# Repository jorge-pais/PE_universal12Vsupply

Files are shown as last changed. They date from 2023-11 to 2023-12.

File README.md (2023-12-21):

# Power Electronics - Final Project

This project is a simple and efficient universal 12V switch mode power supply circuit, designed and built for the final project of the Power Electronics Course at KU Leuven - Group T. It is designed around Texas Instruments' LM5175 buck-boost controller IC in order to provide currents up to 2A with an input voltage ranging from 4V to 24V.

## Circuit and PCB

Both the schematic capture and PCB design were done utilizing KiCad 7. These project files can be found the `universal12Vsupply` folder.

It is possible to preview the project online without KiCad through [KiCanvas](https://kicanvas.org/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).

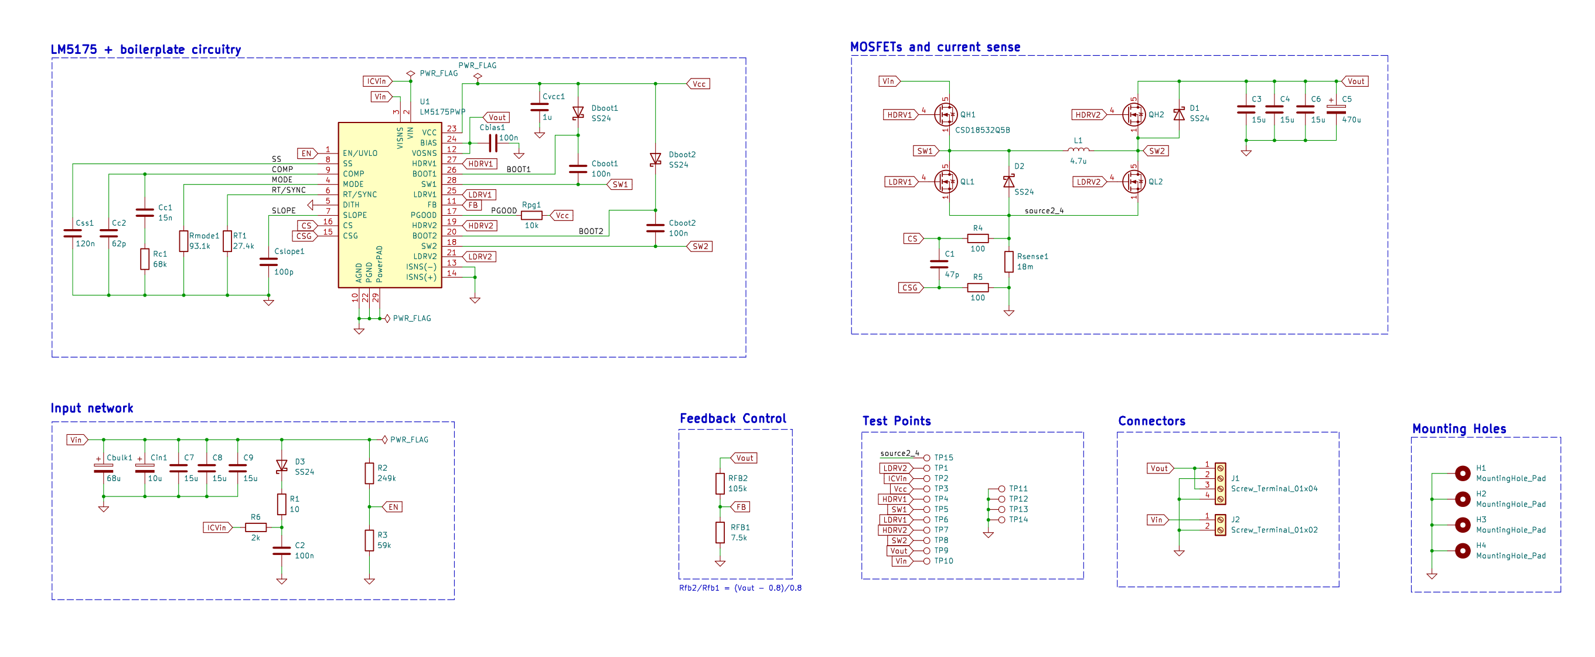
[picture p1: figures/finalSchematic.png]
Circuit schematic


#### Front View

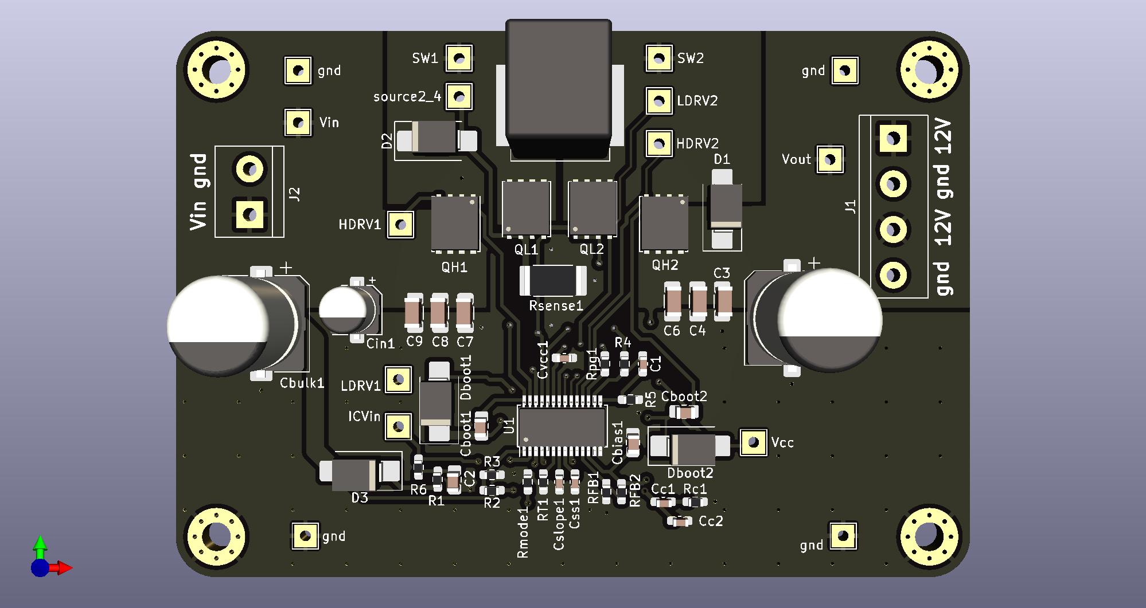
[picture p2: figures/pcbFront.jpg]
Front view of the PCB


#### Back View

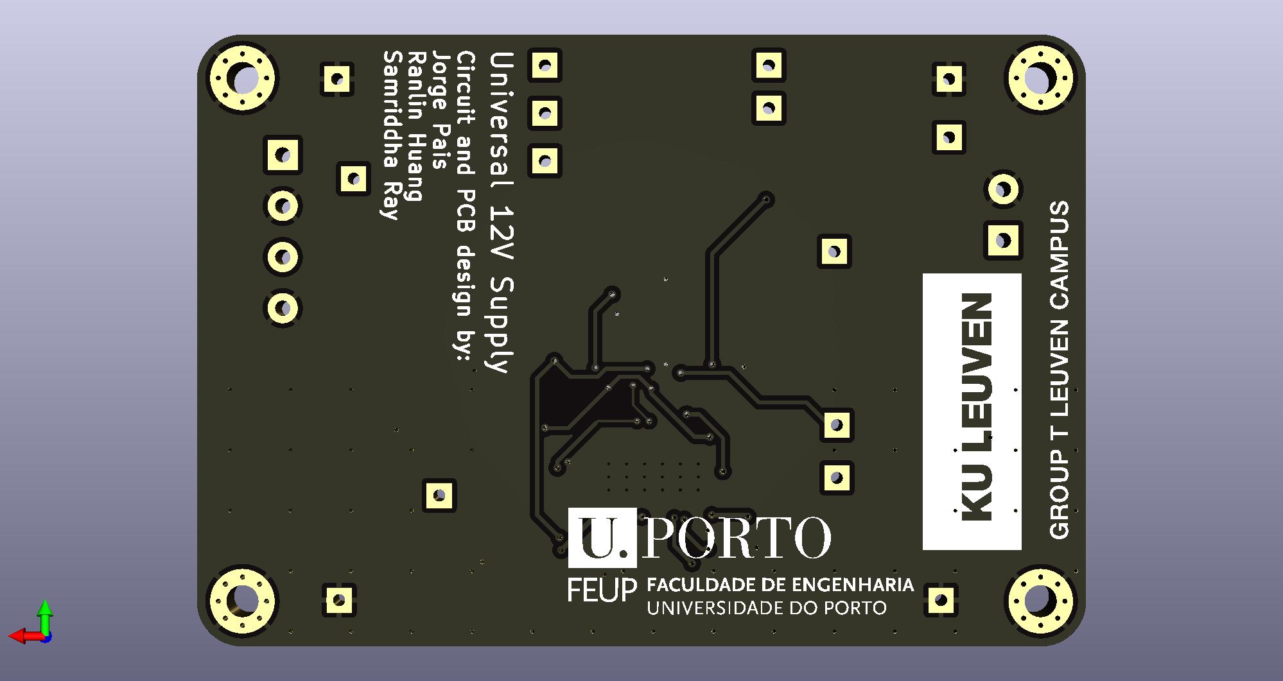
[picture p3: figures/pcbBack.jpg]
Back view of the PCB


## Credits

This project was the collaborative effort of the following team members:

- Jorge Pais
- Ranlin Huang
- Samriddha Ray

Their hard work and dedication made this project a success.

## License

This project is licensed under the [Open Source Hardware License 2](LICENSE.md)

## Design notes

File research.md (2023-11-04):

# Power Electronics Project

***Theme:*** Universal 12V supply. IN: 5-18V. OUT: 12V, 1A

For all the calculations, the components were overdimensioned considering IN: 4-24V and Iout of 2A  

Given the input/output requirements, a step-up-down configuration is needed. By looking at some major manufacturers of power management ICs, the LM5176 buck-boost controller was chosen because although it requires external switching through MOSFETs.

https://be.farnell.com/en-BE/texas-instruments/lm5176pwpt/dc-dc-ctrl-sync-buck-boost-htssop/dp/3008671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

In the datasheet, a simple buck boost implementation is shown as figure 8-1.

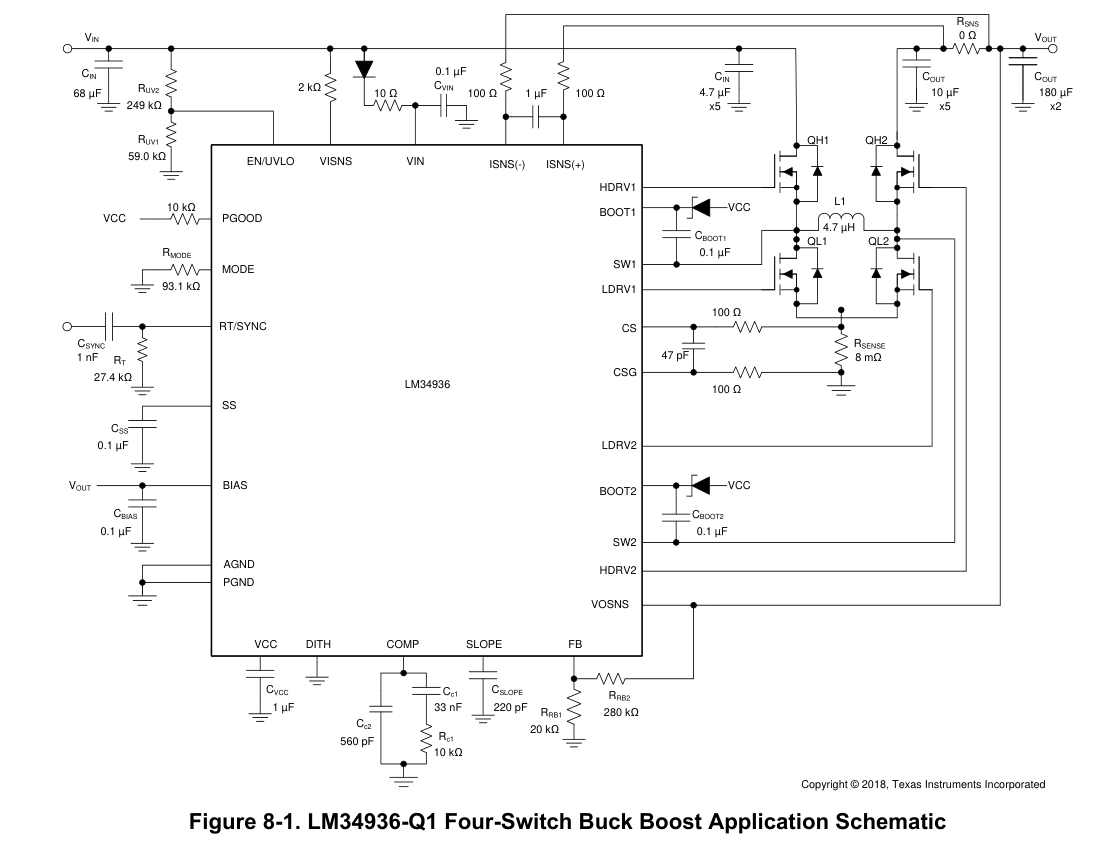
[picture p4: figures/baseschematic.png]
Buck Boost Application Schamatic


### Design

#### Frequency

As per the majority datasheet information and examples, we'll use a switching frequency $F_{SW} = 300 \text{kHz}$. As such, the $R_{T}$ resistor must be of value $27.4\text k \Omega$.

#### Vout

The output voltage is set using a resistor devider to the FB pin. The internal reference voltage is 0.8V.

$$\frac{R_{FB2}}{R_{FB1}} = \frac{V_{out}-0.8}{0.8} = 14$$

If we use resistors from the E48 value series we get a perfect resistor ratio using:

$$R_{FB1} = 7.5 \text k \Omega; R_{FB2} = 105 \text k \Omega$$

#### Inductor Selection

The target inductance for Buck mode is:

$$L_{buck} = \frac{(V_{inMAX}-V_{out})V_{out}}{0.4I_{outMAX}F_{SW}V_{inMAX}} = 25 \mu \text H$$

And the target inductance for boost mode is:

$$L_{boost} = \frac{V_{inMIN}^2 (V_{out}-V_{inMIN})}{0.3I_{outMAX}F_{SW}V_{out}^2}= 4.93 \mu \text H$$

And the maximum average inductor current is (assuming 90\%) efficiency:

$$I_{Lmax} = \frac{V_{out}I_{outMAX}}{0.9V_{inMIN}}= 6.66\text A$$

Given this, and that the datasheet also under specs this component quite a bit, the following $4.7\mu \text H$ inductor can be utilized: https://be.farnell.com/en-BE/bourns/srp1038a-4r7m/inductor-4-7uh-20-10a-shielded/dp/2434028

$$I_{Lpeak} = I_{Lmax} \frac{V_{inMIN}(V_{out}-V_{inMIN})}{2L_1F_{sw}V_{out}} \approx 6.66 \text A$$

#### Output Capacitor

The output capacitor can be determined by the capacitive ripple voltage:

$$\Delta V_{ripple} = \frac{I_{out}(1-\frac{V_{inMIN}}{V_{out}})}{C_{out}F_{SW}}$$

So for a 10 mV ripple from the capacitor, a value of $444.44\mu \text F$ is required. As such $C_{out} = 470\mu \text F$  

#### MOSFETs
The csd18532 is a good mosfet option with high current handling capabilities and and enough Vds to handle the maximum input voltage.
https://be.farnell.com/en-BE/texas-instruments/csd18532q5b/mosfet-n-ch-60v-100a-vson-8/dp/3009663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

#### Rsense

$$R_{senseBUCK} = \frac{80\text{mV}}{I_{outMAX}} = 40\text m\Omega$$

$$R_{senseBOOST} = \frac{120\text{mV}}{I_{Lpeak}} = 18\text m\Omega$$

This value is then set to $R_{sense} = 18\text m\Omega$ based on the boost mode operation.

The power loss experienced by the $R_{sense}$ is the following:

$$P_{senseMAX} = (120mV/R_{sense})^2*R_{sense}*(1-V_{inMIN}/V_{out}) = 0.53 \text W$$

Hence a 1W sense resistor is sufficient

#### Frequency Compensation

At the maximum load of 2A, output resistance is $R_{out} = V_{out}/I_{outMAX} 6\Omega$

$$f_{p1(boost)} = \frac{2}{2\pi R_{out}C_{out}} = 112 \text{Hz}$$

$$f_{z1} = \frac{1}{2\pi R_{esr}C_{out}} = 226 \text{Hz} $$

The boost power stage RHP zero location is given by: 

$$f_{RHP} = \frac{R_{out}(1-D_{max})^2}{2\pi L_1} = 22.57\text{kHz}$$

Where $D_{max}$ is the maximum duty cycle at the minimum $V_{in}$: $D = 1-\frac{V_i}{V_o} = 0.667$ 

$$f_{p1(buck)} = \frac{1}{2\pi R_{out}C_{out}} = 56.4379$$

From these, it is clear that the RHP zero is the main factor limiting the achievable bandwidth.

$$f_{bw} = \frac{f_{RHP}}{3} = 7.52\text{kHz}$$

The compensation zero can be placed at 1.5 times the boost frequency pole.

$$f_{zc} = 1.5f_{p1(boost)} = 168\text{Hz}$$

Then the values for $R_{c1}, C_{c1} and C_{c2}$ can be figured out through the following expressions:

$$R_{c1} = \frac{2\pi f_{bw}}{gm_{EA}}\frac{R_{FB1}+R_{FB2}}{R_{FB1}}\frac{A_{cs}R_{sense}C_{out}}{1-D_{max}} = 68656\Omega \approx 68\text k \Omega$$

$$C_{c1} = \frac{1}{2\pi f_{zc} R_{c1}} = 13.79 \text{nF} \approx 13 \text{nF}$$

$$C_{c2} = \frac{1}{2\pi 5 f_{bw} R_{c1}} = 61.65 \text{pF} \approx 62 \text{pF}$$

#### Soft start

For a 20ms soft-start:

$I_{ss} = 5\mu \text A$

$$C_{ss} = \frac{t_{ss}I_{ss}}{V_{ref}} = 125 nF = 120n $$

#### Slope compensation

$$C_{slope} = gm_{slope}\frac{L1}{R_{sense}A_{cs}} = 100pF$$

#### Diodes

For all the diodes needed by the circuit, the MULTICOMP PRO SS24 schottky barrier rectifier was selected:

https://be.farnell.com/en-BE/multicomp/ss24/schottky-rectifier-2a-40v-do-214aa/dp/2675138?MER=sy-me-pd-mi-alte

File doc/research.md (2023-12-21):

# Power Electronics Project - Design

***Theme:*** Universal 12V supply. IN: 5-18V. OUT: 12V, 1A

For all the calculations, the components were overdimensioned considering IN: 4-24V and Iout of 2A  

Given the input/output requirements, a step-up-down configuration is needed. By looking at some major manufacturers of power management ICs, the LM5176 buck-boost controller was chosen because although it requires external switching through MOSFETs.

https://be.farnell.com/en-BE/texas-instruments/lm5176pwpt/dc-dc-ctrl-sync-buck-boost-htssop/dp/3008671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

In the datasheet, a simple buck boost implementation is shown as figure 8-1.

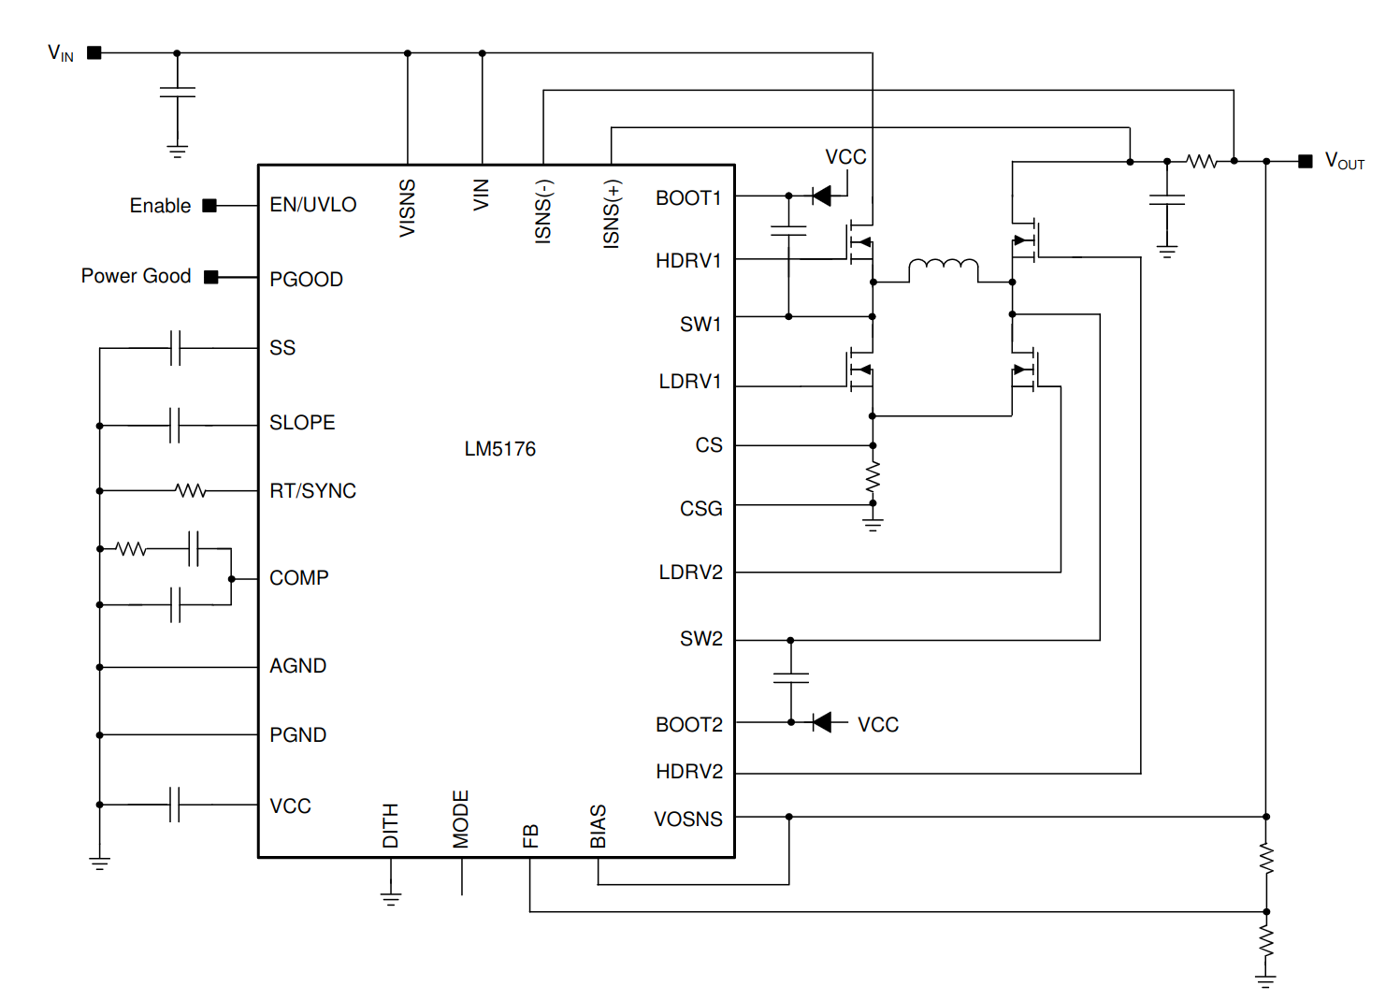
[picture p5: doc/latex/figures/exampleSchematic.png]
Buck Boost Application Schamatic


### Design

#### Frequency

As per the majority datasheet information and examples, we'll use a switching frequency $F_{SW} = 300 \text{kHz}$. As such, the $R_{T}$ resistor must be of value $27.4\text k \Omega$.

#### Vout

The output voltage is set using a resistor devider to the FB pin. The internal reference voltage is 0.8V.

$$\frac{R_{FB2}}{R_{FB1}} = \frac{V_{out}-0.8}{0.8} = 14$$

If we use resistors from the E48 value series we get a perfect resistor ratio using:

$$R_{FB1} = 7.5 \text k \Omega; R_{FB2} = 105 \text k \Omega$$

#### Inductor Selection

The target inductance for Buck mode is:

$$L_{buck} = \frac{(V_{inMAX}-V_{out})V_{out}}{0.4I_{outMAX}F_{SW}V_{inMAX}} = 25 \mu \text H$$

And the target inductance for boost mode is:

$$L_{boost} = \frac{V_{inMIN}^2 (V_{out}-V_{inMIN})}{0.3I_{outMAX}F_{SW}V_{out}^2}= 4.93 \mu \text H$$

And the maximum average inductor current is (assuming 90\%) efficiency:

$$I_{Lmax} = \frac{V_{out}I_{outMAX}}{0.9V_{inMIN}}= 6.66\text A$$

Given this, and that the datasheet also under specs this component quite a bit, the following $4.7\mu \text H$ inductor can be utilized: https://be.farnell.com/en-BE/bourns/srp1038a-4r7m/inductor-4-7uh-20-10a-shielded/dp/2434028

$$I_{Lpeak} = I_{Lmax} + \frac{V_{inMIN}(V_{out}-V_{inMIN})}{2L_1F_{sw}V_{out}} \approx 6.66 \text A$$

#### Output Capacitor

The output capacitor can be determined by the capacitive ripple voltage:

$$\Delta V_{ripple} = \frac{I_{out}(1-\frac{V_{inMIN}}{V_{out}})}{C_{out}F_{SW}}$$

So for a 10 mV ripple from the capacitor, a value of $444.44\mu \text F$ is required. As such $C_{out} = 470\mu \text F$  

#### MOSFETs
The csd18532 is a good mosfet option with high current handling capabilities and and enough Vds to handle the maximum input voltage.
https://be.farnell.com/en-BE/texas-instruments/csd18532q5b/mosfet-n-ch-60v-100a-vson-8/dp/3009663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

#### Rsense

$$R_{senseBUCK} = \frac{80\text{mV}}{I_{outMAX}} = 40\text m\Omega$$

$$R_{senseBOOST} = \frac{120\text{mV}}{I_{Lpeak}} = 18\text m\Omega$$

This value is then set to $R_{sense} = 18\text m\Omega$ based on the boost mode operation.

The power loss experienced by the $R_{sense}$ is the following:

$$P_{senseMAX} = (120mV/R_{sense})^2*R_{sense}*(1-V_{inMIN}/V_{out}) = 0.53 \text W$$

Hence a 1W sense resistor is sufficient

#### Frequency Compensation

At the maximum load of 2A, output resistance is $R_{out} = V_{out}/I_{outMAX} 6\Omega$

$$f_{p1(boost)} = \frac{2}{2\pi R_{out}C_{out}} = 112 \text{Hz}$$

$$f_{z1} = \frac{1}{2\pi R_{esr}C_{out}} = 226 \text{Hz} $$

The boost power stage RHP zero location is given by: 

$$f_{RHP} = \frac{R_{out}(1-D_{max})^2}{2\pi L_1} = 22.57\text{kHz}$$

Where $D_{max}$ is the maximum duty cycle at the minimum $V_{in}$: $D = 1-\frac{V_i}{V_o} = 0.667$ 

$$f_{p1(buck)} = \frac{1}{2\pi R_{out}C_{out}} = 56.4379$$

From these, it is clear that the RHP zero is the main factor limiting the achievable bandwidth.

$$f_{bw} = \frac{f_{RHP}}{3} = 7.52\text{kHz}$$

The compensation zero can be placed at 1.5 times the boost frequency pole.

$$f_{zc} = 1.5f_{p1(boost)} = 168\text{Hz}$$

Then the values for $R_{c1}, C_{c1} and C_{c2}$ can be figured out through the following expressions:

$$R_{c1} = \frac{2\pi f_{bw}}{gm_{EA}}\frac{R_{FB1}+R_{FB2}}{R_{FB1}}\frac{A_{cs}R_{sense}C_{out}}{1-D_{max}} = 68656\Omega \approx 68\text k \Omega$$

$$C_{c1} = \frac{1}{2\pi f_{zc} R_{c1}} = 13.79 \text{nF} \approx 13 \text{nF}$$

$$C_{c2} = \frac{1}{2\pi 5 f_{bw} R_{c1}} = 61.65 \text{pF} \approx 62 \text{pF}$$

#### Soft start

For a 20ms soft-start:

$I_{ss} = 5\mu \text A$

$$C_{ss} = \frac{t_{ss}I_{ss}}{V_{ref}} = 125 nF = 120n $$

#### Slope compensation

$$C_{slope} = gm_{slope}\frac{L1}{R_{sense}A_{cs}} = 100pF$$

#### Diodes

For all the diodes needed by the circuit, the MULTICOMP PRO SS24 schottky barrier rectifier was selected:

https://be.farnell.com/en-BE/multicomp/ss24/schottky-rectifier-2a-40v-do-214aa/dp/2675138?MER=sy-me-pd-mi-alte

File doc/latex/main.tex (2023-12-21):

\documentclass[11pt, a4paper]{article}

\usepackage[T1]{fontenc}
\usepackage[utf8]{inputenc}

\usepackage{verbatim}
\usepackage{amsmath}
%\usepackage{biblatex} 
\usepackage{graphicx}   
\usepackage{float}
\usepackage{appendix}   
\usepackage{listings}   
\usepackage{xcolor}
\usepackage{siunitx}
\usepackage{pdfpages}
\usepackage{textcomp, gensymb}
\usepackage{multirow}

\sisetup{detect-all}

\usepackage[
backend=biber,
style=ieee,
sorting=ynt
]{biblatex}

\addbibresource{1.bib}

\title{Power Electronics - 12V Universal Supply \\ Design and Measurement Report}
\author{Jorge Pais \\ Ranlin Huang \\ Samriddha Ray }
\date{December 2023}

\begin{document}

\maketitle
\vfill \pagebreak
\tableofcontents
\vfill \pagebreak

\section{Introduction/Specification}

Our project proposed for the power electronics course unit was the universal 12V power supply. The original specifications were as follows:

\begin{itemize}
    \item Output voltage: 12V
    \item Input voltage : min. 5V; max. 18V
    \item Output Current: 1A 
\end{itemize}

Considering these, the team attempted to overdimension the circuit in order to output more current (2A) and accept a higher range of input voltages (min. 5V and max. 24V).

\section{Design}

\subsection{Circuit}

As the basis for the design, the LM5175 buck-boost converter controller by Texas Instruments \cite{lm7175data} was chosen. Since the design requires 2A of output current, a externally switched solution is a safer approach and as such the LM5175 presents a relatively modern design without many features such as $\text I^2\text C$ that would not be utilized. Also the four switch buck-boost converter approach as some advantages over traditional single or dual switch topologies, since at any given time two of the MOSFETs are in either on or off state while the other commutate. This has the benefit that no diodes are needed, and thus lower forward voltage drops are present in both modes of operation.

An example circuit schematic for the circuit can be seen in figure \ref{fig:exampleSchem}. The circuit developed is based around this initial design and uses follows the dimensioning procedure that is described in the IC's datasheet \cite{lm7175data}.

\begin{figure}[H]
    \centering
    
    \caption{Simplified LM5175 Schematic}
    \label{fig:exampleSchem}
\end{figure}

As for the final schematic, a simplified version without connectors and testpoints can be found at the end of this document as an appendix.

\subsubsection{Switching Frequency}

The LM5175's switching frequency can be programmed between 100 and 600 kHz using a resistor from the RT/SYNC pin to ground. Higher values lead to higher overall efficiency but with added EMI and noise. The switching frequency was chosen to be 300kHz, as most examples featured in the datasheet used this value.

\begin{equation}
    R_T = \frac{1/F_{SW}-190\text{ns}}{116\text{pF}} = 27.4 \text k \Omega
\end{equation}

\subsubsection{Feedback Network}

The output voltage of the circuit is set using a the feedback network between the output and the IC's FB pin. 

\begin{equation}
    \frac{R_{FB2}}{R_{FB1}} = \frac{V_{out}-0.8}{0.8} = 14
\end{equation}

Choosing E48 series resistor values, a perfect ratio can be obtained:

$$R_{FB1} = 7.5 \text k \Omega; R_{FB2} = 105 \text k \Omega$$

\subsubsection{Inductor Selection}

The target inductance for Buck mode is given by the following formula:

\begin{equation}
    L_{buck} = \frac{(V_{inMAX}-V_{out})V_{out}}{0.4I_{outMAX}F_{SW}V_{inMAX}} = 25 \mu \text H
\end{equation}

And the target for boost mode is the following:

\begin{equation}
    L_{boost} = \frac{V_{inMIN}^2 (V_{out}-V_{inMIN})}{0.3I_{outMAX}F_{SW}V_{out}^2}= 4.93 \mu \text H
\end{equation}

The maximum average inductor current is the following if we assume 90\% efficiency:

\begin{equation}
    I_{Lmax} = \frac{V_{out}I_{outMAX}}{0.9V_{inMIN}}= 6.66\text A
\end{equation}

Given this, the datasheet actually under specifies this component. A $4.7\mu \text H$ inductor can be utilized and as such, the XAL1010-472MED from Coilcraft \cite{XAL1010data} was chosen.

As for the peak inductor following through the inductor it is:

\begin{equation}
    I_{Lpeak} = I_{Lmax} + \frac{V_{inMIN}(V_{out}-V_{inMIN})}{2L_1F_{sw}V_{out}} \approx 6.66 \text A  
\end{equation}

\subsubsection{Output Capacitors}

The value for the main output capacitor can be determined by the capacitive ripple voltage:

\begin{equation}
    \Delta V_{ripple} = \frac{I_{out}(1-\frac{V_{inMIN}}{V_{out}})}{C_{out}F_{SW}}
\end{equation}

And so, for a 10mV ripple from the capacitor, a value of $444.44\mu \text F$ is required. As such $C_{out} = 470\mu \text F$, which can be achieved with a small electrolytic capacitor. For this purpose Panasonic's 25SPVK470M Polymer Aluminum capacitor was chosen, which has a maximum voltage rating of 25V and a ESR of 14m$\Omega$.

Along side this, three smaller $15\mu \text F$ tantalum capacitors are placed in parallel, such as to minimize output ESR. So, the TPSA156K006R0700 from Kyocera Avx was chosen, each featuring an ESR of 7m$\Omega$. 

For the boost mode of operation the RMS current through the capacitor is given by:

\begin{equation}
    I_{Cout_{RMS}} = I_{out} \sqrt{\frac{V_{out}}{V_{in}}-1}
    \label{eq:coutIrms}
\end{equation}

\subsubsection{Input Capacitors}

As for the input capacitors, in the buck operating region, they need to be able to supply high ripple current. It's RMS current is given by the following equation, where the worst case scenario of D = 0.5 should be considered:

\begin{equation}
    I_{C_{in}rms} = I_{out} \sqrt{D(1-D)} = 1 A
    \label{eq:cinIrms}
\end{equation}

So in a similar fashion as for the output, a bulk electrolytic capacitor of $68\mu \text F$ was placed in parallel with several $15\mu \text F$ tantalum capacitors. The bulk capacitor chosen was the Panasonic EEHZT1J680P featuring a maximum voltage rating of 63V and a ESR of 25m$\Omega$.

\subsubsection{Current Limit}

The circuit's current limit is set by the $R_{sense}$ resistor at the tail of the 4 mosfet switch bridge.

\begin{equation}
    R_{senseBUCK} = \frac{80\text{mV}}{I_{outMAX}} = 40\text m\Omega
\end{equation}

\begin{equation}
    R_{senseBOOST} = \frac{120\text{mV}}{I_{Lpeak}} = 18\text m\Omega
\end{equation}

This value is then set to $R_{sense} = 18\text m\Omega$ based on the boost mode operation. The power loss experienced by the $R_{sense}$ is the following:

\begin{equation}
    P_{senseMAX} = \left (\frac{120mV}{R_{sense}}\right )^2R_{sense}\left (1-\frac{V_{inMIN}}{V_{out}}\right ) = 0.53 \text W
    \label{eq:rsensePower}
\end{equation}

Hence a 1W sense resistor is sufficient. As for the sense lines $R_{CS}$ and $R_{CSG}$ the values were chosen according to the example schematic provided on the datasheet: $R_{CS} = R_{CSG} = 100\Omega$. A filter capacitor is also needed to attenuate the noise that can occur in these lines due to the large amounts of current passing through $R_{sense}$, as such a 47pF capacitor is utilized as a part of a differential mode filter in the CS and CSG pins to the LM5175.

\subsubsection{MOSFETs}

The LM5175 features four built-in N-channel MOSFET gate drivers. In buck operation, QL1 and QH1 are switched by the IC's PWM controller while QH2 is continuously on and QL2 off. As for boost operation, QL2 and QH2 are switching while QH1 remains continuously on and QL2 is off.

For the QH1 and QL2 MOSFETs on the input side, these need to withstand the maximum input voltage of the circuit, plus the possible voltage transient spikes. Considering the extended specifications, this value comes to $V_{DS_{max}} \ge 24 + 20V$. As for the output, transistors QH2 and QL2 should be rated for 12V plus the transient spikes.

When choosing a MOSFET for this circuit, it is also important to consider the rise/fall time and gate charges of the transistor, in order to minimize switching time and thus minimize switching loss. Also, the drain-to-source on-resistance should be minimal in order to lower the conduction losses.

Considering these requirements, the MOSFET chosen for the 4 switches was the Texas Instruments' CSD18532Q5B n-channel MOSFET \cite{CSD18532data}, claiming to feature maximum $V_{gs}$ of 60V and ultra-low gate charges.

\subsubsection{Frequency Compensation}

At the maximum load of 2A, output resistance is $R_{out} = V_{out}/I_{outMAX} 6\Omega$

\begin{equation}
    f_{p1(boost)} = \frac{2}{2\pi R_{out}C_{out}} = 112 \text{Hz}    
\end{equation}

\begin{equation}
    f_{z1} = \frac{1}{2\pi R_{esr}C_{out}} = 226 \text{Hz}    
\end{equation}

The boost power stage RHP zero location is given by: 

\begin{equation}
    f_{RHP} = \frac{R_{out}(1-D_{max})^2}{2\pi L_1} = 22.57\text{kHz}
\end{equation}

Where $D_{max}$ is the maximum duty cycle at the minimum $V_{in}$: $D = 1-\frac{V_i}{V_o} = 0.667$ 

\begin{equation}
    f_{p1(buck)} = \frac{1}{2\pi R_{out}C_{out}} = 56.4379  
\end{equation}

From these, it is clear that the RHP zero is the main factor limiting the achievable bandwidth.

\begin{equation}
    f_{bw} = \frac{f_{RHP}}{3} = 7.52\text{kHz}    
\end{equation}

The compensation zero can be placed at 1.5 times the boost frequency pole.

\begin{equation}
    f_{zc} = 1.5f_{p1(boost)} = 168\text{Hz}  
\end{equation}

Then the values for $R_{c1}, C_{c1}$ and $C_{c2}$ can be figured out through the following expressions:

\begin{equation}
    R_{c1} = \frac{2\pi f_{bw}}{gm_{EA}}\frac{R_{FB1}+R_{FB2}}{R_{FB1}}\frac{A_{cs}R_{sense}C_{out}}{1-D_{max}} = 68656\Omega \approx 68\text k \Omega  
\end{equation}

\begin{equation}
    C_{c1} = \frac{1}{2\pi f_{zc} R_{c1}} = 13.79 \text{nF} \approx 13 \text{nF}    
\end{equation}

\begin{equation}
    C_{c2} = \frac{1}{2\pi 5 f_{bw} R_{c1}} = 61.65 \text{pF} \approx 62 \text{pF}    
\end{equation}

\subsubsection{Boilerplate Circuitry}

In order to turn-on the IC, an appropriate voltage divider has to be built around the Enable/UVLO pin of the LM5175, which also functions as an undervoltage lockout, providing hysteresis between the turn-on and turn-off voltages. Using the following equation, the E96 values for the resistors can be calculated:

\begin{eqnarray}
    \begin{cases}
        V_{UV} = V_{en} \left (1 + \frac{R_{UV1}}{R_{UV2}}\right ) - R_{UV2}I_{en} \\
        R_{UV1} = 59\text k\Omega; R_{UV1} = 249\text k\Omega 
    \end{cases}
\end{eqnarray}

The LM5175 also features what is called soft start, which charges an external capacitor whenever the converter is powered up, replacing the internal reference voltage for the feedback in the error amplifier. Once fully charged, the internal error amplifier is then referenced to $V_{ref}$ again.

A 20ms soft-start should be plenty for this circuit:

\begin{equation}
    \begin{cases}
        I_{ss} = 5\mu \text A \\        
        C_{ss} = \frac{t_{ss}I_{ss}}{V_{ref}} = 125 \text{nF} \approx 120 \text{nF} \\
    \end{cases}
\end{equation}

Apart from the frequency compensation dimensioned previously, slope compensation is also an important step in the design of any current-mode controlled converters in order to avoid oscillations. For the case of the LM5175 it should be dimensioned as such:

\begin{equation}
    C_{slope} = g_{m_{slope}}\frac{L1}{R_{sense}A_{cs}} = 100\text{pF}    
\end{equation}

Finally, the bootstrap capacitors and diodes also have to be chosen in order for the integrated MOSFET drivers to function as intended. For this purpose, 100nF ceramic caps were chosen. Also the SS24 Schottky Barrier Rectifier by Multicomp Pro was decided upon for the diodes due to it's 2A forward current and 40V peak reverse voltage \cite{SS24data}. It doesn't matter all that much as long as it's a schottky, but this diode was chosen also because it could withstand the possible peak voltages from the MOSFET bridge, and reusing it throughout the circuit reduces the final BOM. 

\subsection{Power Losses \& Efficiency}

\subsubsection{MOSFETs}

In the buck mode of operation, the conduction and switching losses are given by the following formulas \cite{lm7175data}:

\begin{equation}
    \begin{cases}
        P_{cond(QH1)} = \frac{V_{out}}{V_{in}}I_{out}^2 R_{DSon} \\
        P_{SW(QH1)} = \frac{1}{2}V_{in}I_{out}(t_r + t_f)F_{SW} \\
        P_{cond(QL1)} = \left (1-\frac{V_{out}}{V_{in}} \right ) I_{out}^2 R_{DSon} \\
        P_{cond(QH2)} = I_{out}^2R_{DSon}
    \end{cases}
\end{equation}

As for when the converter is operating in boost mode:

\begin{equation}
    \begin{cases}
        P_{cond(QH1)} = \left (\frac{V_{out}}{V_{in}}I_{out} \right )^2 R_{DSon} \\
        P_{cond(QL2)} = \left (1 - \frac{V_{out}}{V_{in}}\right ) \left (\frac{V_{out}}{V_{in}}I_{out} \right )^2 R_{DSon} \\
        P_{SW(QL2)} = \frac{1}{2}V_{out}\left (\frac{V_{out}}{V_{in}}I_{out} \right )(t_r + t_f)F_{SW} \\
        P_{cond(QH2)} = \frac{V_{in}}{V_{out}}\left (I_{out}\frac{V_{out}}{V_{in}} \right )^2 R_{DSon}
    \end{cases}
\end{equation}

If we plug some of the datasheet specifications into the power loss equations, along with the worst case values for $V_{in}$ and $I_{out}$ then the results on table \ref{tab:mosfetLosses} are obtained. It should be taken into account that the actual rise/fall switching times have to be determined empirically in the lab, so the values used consider a much higher current than what our circuit consumes.

\begin{table}[H]
    \centering
    \begin{tabular}{|c|c|c|c|}
        \hline
        \multicolumn{2}{|c|}{Buck} & \multicolumn{2}{|c|}{Boost} \\
        \hline \hline
        $P_{cond(QH1)}$ & $8.6$mW  & $P_{cond(QH1)}$ & $99.1$mW \\
        $P_{SW(QH1)}$   & $74.2$mW & $P_{cond(QL2)}$ & $57.8$mW \\
        $P_{cond(QL1)}$ & $8.6$mW  & $P_{SW(QL2)}$   & $59.4$mW \\
        $P_{cond(QH2)}$ & $17.2$mW & $P_{cond(QH2)}$ & $41.3$mW \\
        \hline
    \end{tabular}
    \caption{Maximum MOSFET Power Losses}
    \label{tab:mosfetLosses}
\end{table}

From these it is also to obtain an idea of the thermal performance of these MOSFETs (table \ref{tab:mosfetTemp}), which even at 2A barely heat up indicating very strong efficiency. This is mostly due to the transistors chosen having both very low gate charges and low $R_{DSon}$.

\begin{table}[H]
    \centering
    \begin{tabular}{|c|c|}
        \hline
        \multirow{2}*{Transistor} & Temperature \\
         & Rise $\Delta T (\degree C)$ \\
        \hline \hline
        $QH1_{Buck}$  & $4.14$ \\
        $QL1_{Buck}$  & $0.43$ \\
        $QH2_{Buck}$  & $0.86$ \\
        $QH1_{Boost}$ & $4.96$ \\
        $QL2_{Boost}$ & $5.86$ \\
        $QH2_{Boost}$ & $2.07$ \\
        \hline
    \end{tabular}
    \caption{Junction-ambient temperature rise}
    \label{tab:mosfetTemp}
\end{table}

Figures \ref{fig:mosfetBuckLosses} and \ref{fig:mosfetBoostLosses} show how these losses are related to both the output current and varying input voltage.

\begin{figure}[H]
    \centering
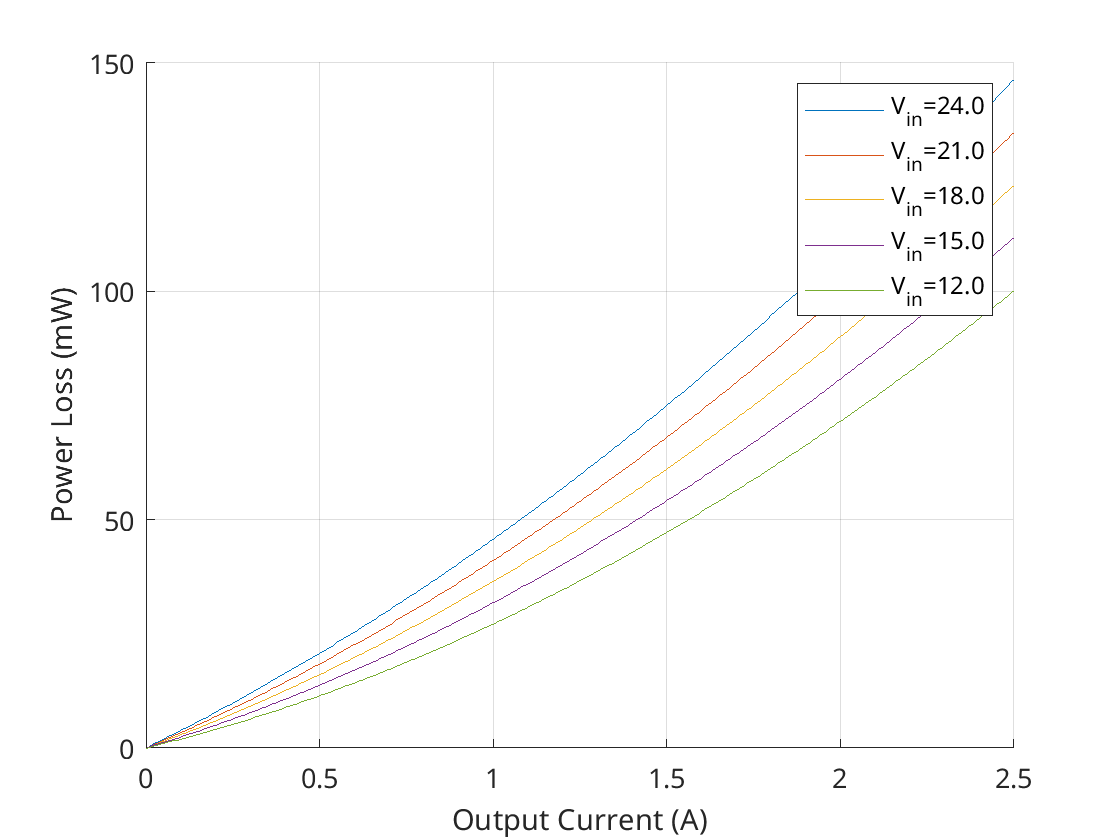
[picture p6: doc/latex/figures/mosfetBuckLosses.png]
    
    \caption{Buck mode MOSFET losses}
    \label{fig:mosfetBuckLosses}
\end{figure}

\begin{figure}[H]
    \centering
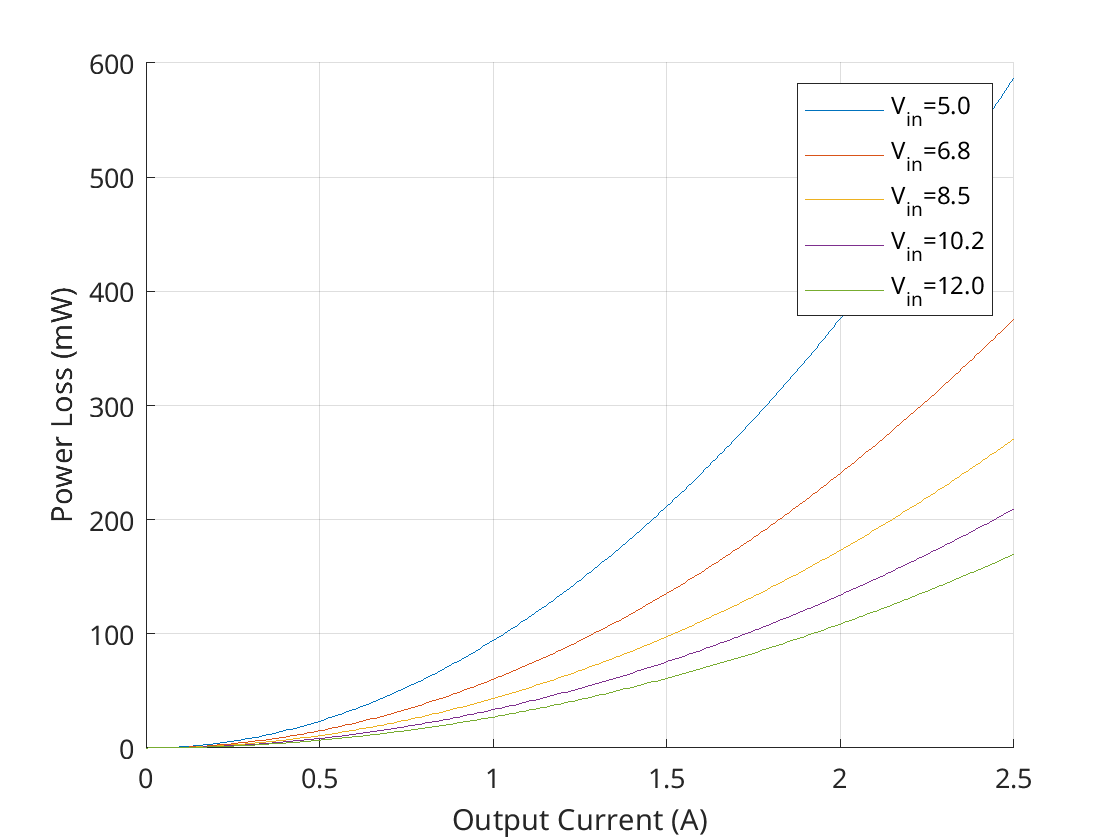
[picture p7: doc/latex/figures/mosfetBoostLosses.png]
    
    \caption{Boost mode MOSFET losses}
    \label{fig:mosfetBoostLosses}
\end{figure}

\subsubsection{Inductor}

Taking the formula for the RMS current through the inductor (with the previous assumption of 90\% efficiency, which certainly is a gross approximation especially when considering lower output currents), an estimate for dissipated power can be obtained if we consider the inductor's wire resistance $R_w = 5.70\text m\Omega$ \cite{XAL1010data}:

\begin{equation}
    P_{inductor} = I_{L_{RMS}}^2 R_w = \left (\frac{V_{out}I_{out}}{0.9V_{in}} \right )^2 R_w
\end{equation}

This gives a maximum power loss when the current is maximum and the input voltage is minimum, with a value of $P_{Lmax} = 162\text{mW}$. In figure \ref{fig:inductorLosses} we can observe the power loss in relation to the output current that is drawn from the converter, for varying input voltages.

\begin{figure}[H]
    \centering
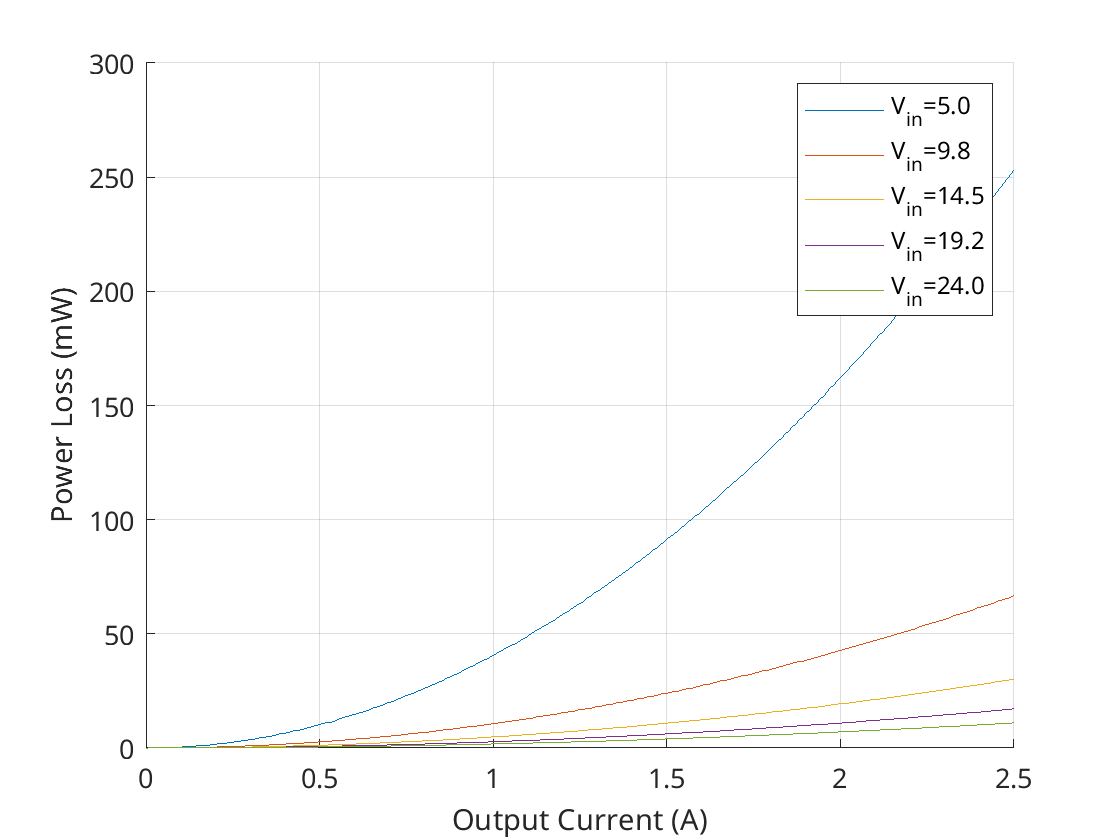
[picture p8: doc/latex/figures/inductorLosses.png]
    
    \caption{Inductor power losses}
    \label{fig:inductorLosses}
\end{figure}

\subsubsection{Capacitor Losses}

During the boost mode of operation the output capacitors are responsible for conducting high ripple current. Using formula \ref{eq:coutIrms} for the output current, capacitor buck-mode power losses can be estimated. The total ESR for the output capacitances is $ESR = 2.0\text m \Omega$.

\begin{equation}
    P_{C_{out}} = I_{C_{rms}}^2 ESR = I_{out}^2 \left (\frac{V_{out}}{V_{in}} - 1 \right ) ESR
\end{equation}

Figure \ref{fig:coutLosses} shows these losses as a function of the output current and the input voltage. It is possible to see that the biggest losses are when the input voltage is minimum where $P_{C_{out}} = 11\text{mW}$.

\begin{figure}[H]
    \centering
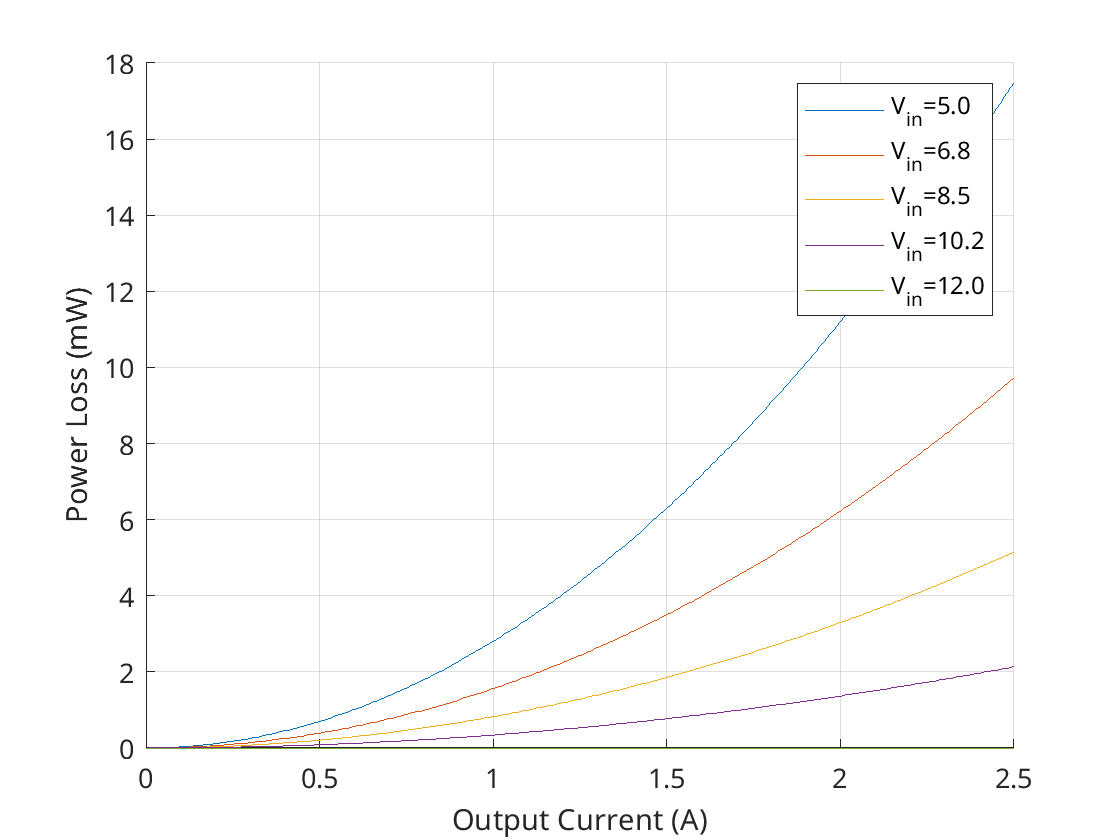
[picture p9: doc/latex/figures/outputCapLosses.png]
    
    \caption{Output capacitor power losses}
    \label{fig:coutLosses}
\end{figure}

As for the input capacitances, the formula for the RMS current in equation \ref{eq:cinIrms} can be utilized to figure out the power losses. The total ESR for the input capacitors is $2.13 \text m \Omega$.

\begin{equation}
    P_{C_{in}} = I_{C_{rms}}^2 ESR = I_{out}^2D(1-D)ESR
\end{equation}

Using this, figure \ref{fig:cinLosses} displays a plot of the power losses in respect to the output current. The maximum power loss is then obtained when the duty cycle is $D=0.5$, where $P_{C_{in}}=2.1\text{mW}$

\begin{figure}[H]
    \centering
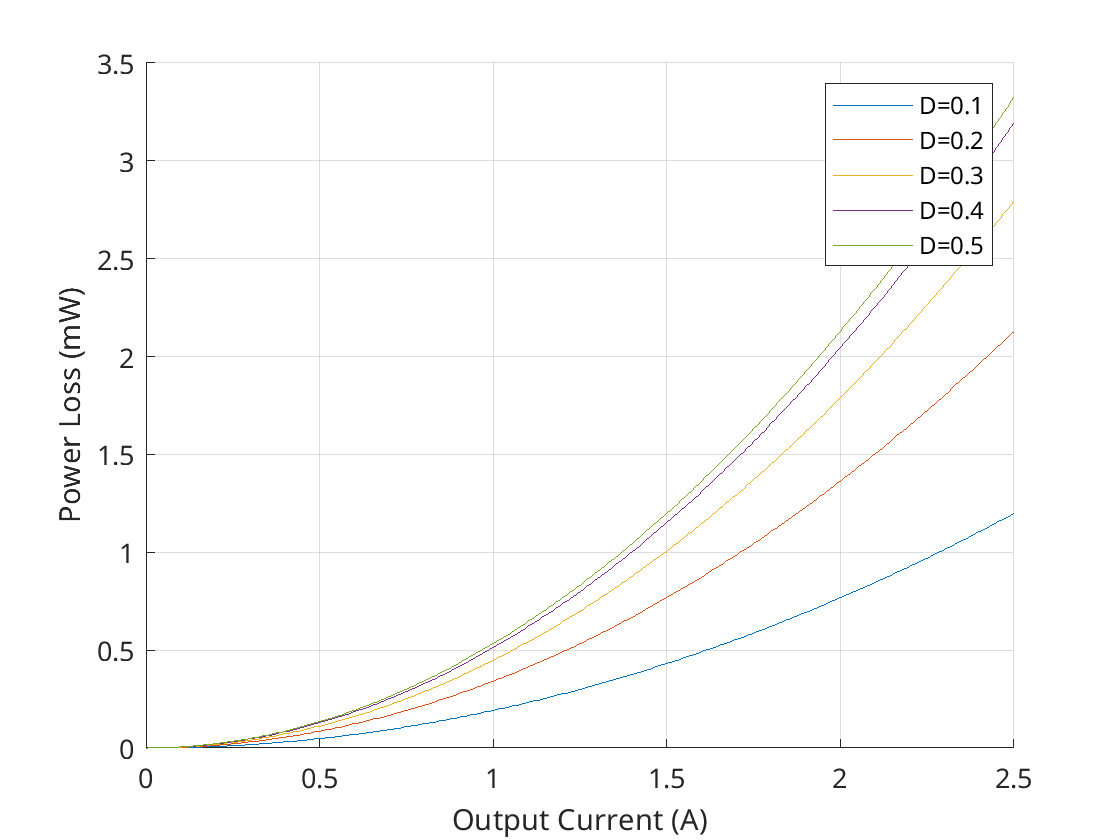
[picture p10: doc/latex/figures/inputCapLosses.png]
    
    \caption{Input capacitor power losses}
    \label{fig:cinLosses}
\end{figure}

\subsubsection{Sense resistor}

A formula for determining the power loss in $R_{sense}$ was already shown in equation \ref{eq:rsensePower}, but only for the boost mode. In this case the power loss was the following, in the worst case scenario:

$$P_{sense_{Boost}} = 530\text{mW}$$

For the buck mode, the formula is pretty much the same, only that the duty cycle is different and now we use the buck current limit threshold $V_{CS(BUCK)} = 80\text{mV}$ for the calculation.

\begin{equation}
    P_{sense_{Buck}} = \left (\frac{80mV}{R_{sense}}\right )^2R_{sense}\left (\frac{V_{out}}{V_{inMAX}}\right ) = 178 \text{mW}
\end{equation}

\subsubsection{Total Losses}

From the previous analysis, the total losses for each mode of operation can be calculated. Firstly the buck mode losses can be seen in figure \ref{fig:totalBuckLosses} which consider the worst case of $V_{in} = 24\text V$. 

\begin{figure}[H]
    \centering
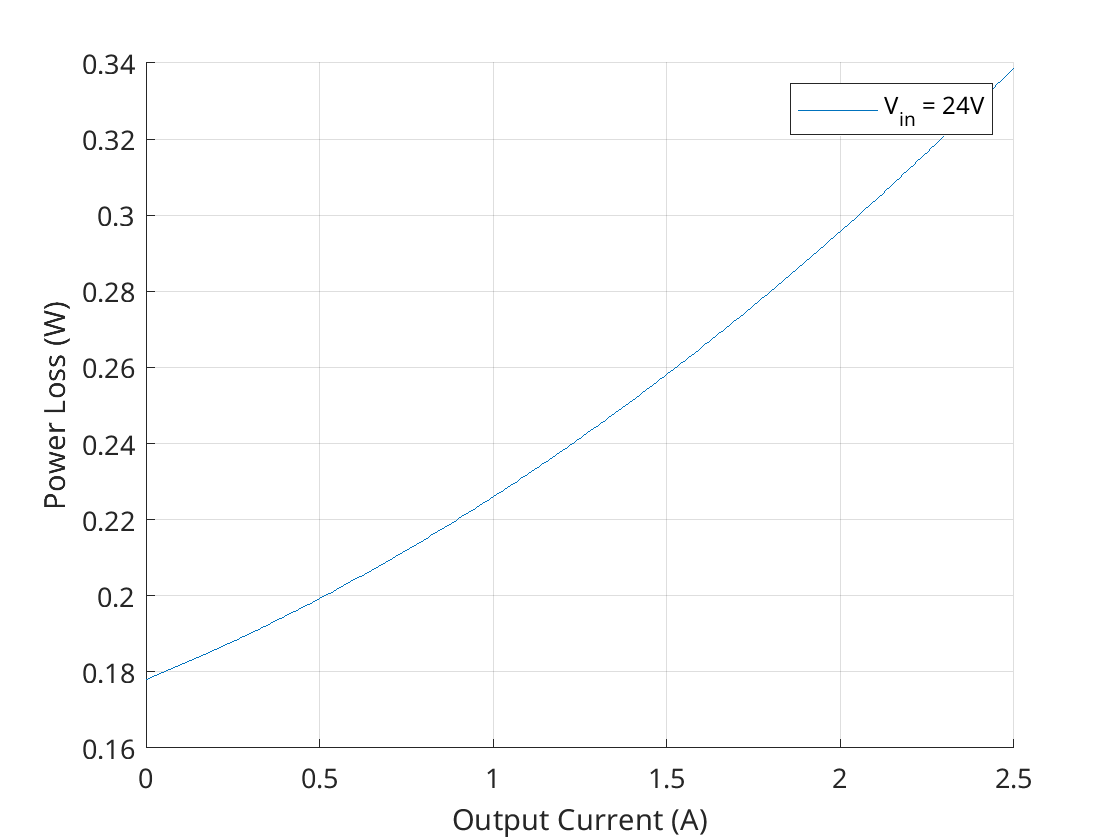
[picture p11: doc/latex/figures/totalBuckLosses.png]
    
    \caption{Total buck mode losses}
    \label{fig:totalBuckLosses}
\end{figure}

Figure \ref{fig:totalBoostLosses} shows the same, but for the boost mode of operation, in the worst case when the input voltage is 5V.

\begin{figure}[H]
    \centering
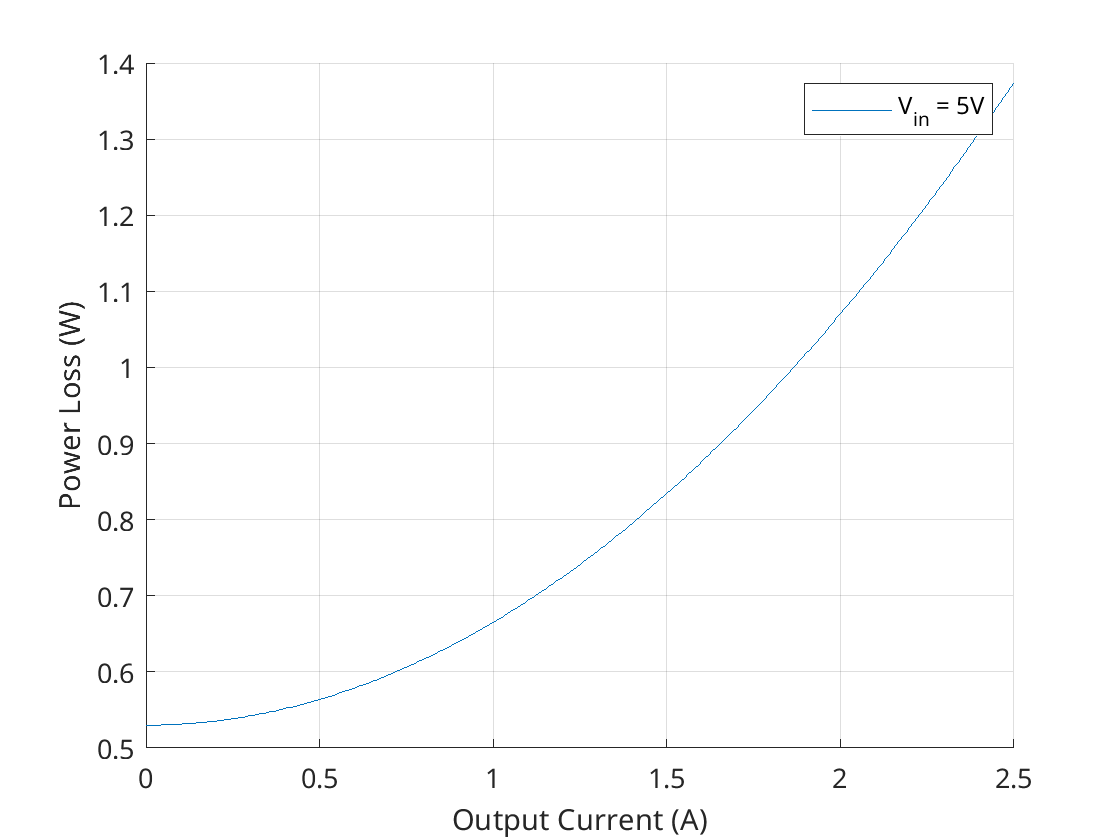
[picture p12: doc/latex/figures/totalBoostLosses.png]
    
    \caption{Total boost mode losses}
    \label{fig:totalBoostLosses}
\end{figure}

\subsubsection{Efficiency}

From the total losses, it is then possible to see what the theoretical efficiency of the converter is. Figure \ref{fig:efficiency} shows the worst case scenario efficiency for both the Boost and Buck modes ($V_{in} = 5\text V$ and $V_{in} = 24\text V$ respectively), as a function of output current.

\begin{figure}[H]
    \centering
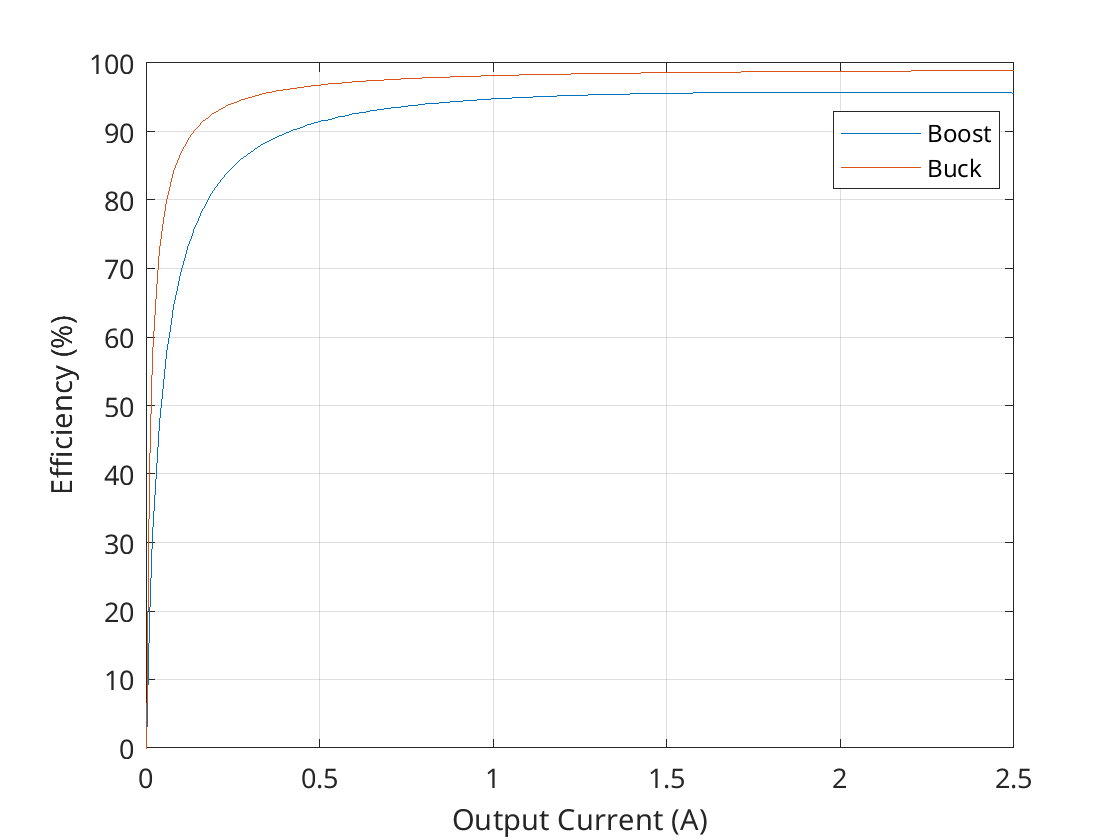
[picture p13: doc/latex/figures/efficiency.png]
    
    \caption{Buck and Boost efficiency}
    \label{fig:efficiency}
\end{figure}

\subsection{Board}

The board was designed utilizing KiCad 7 for both the schematic capture and PCB layout. Some of the specifications for the board were based on the project limitations and the constraints posed by JLCPCB manufacturing. These were was follows:

\begin{itemize}
    \item 2 layers, bottom GND plane
    \item SMD only, except for connectors/testpoints
    \item Min. copper clearence: 0.2mm
    \item Min. track width: 0.2mm
    \item Min. annular width: 0.13mm
    \item Min. via diameter: 0.7mm
    \item Min. copper to hole clearence: 0.25mm
    \item Min. through-hole diameter: 0.3mm
    \item Min. hole-to-hole clearence: 0.254mm
\end{itemize}

Considering these, a relatively simple and compact layout was achieved, whose routing can be seen in figure \ref{fig:pcbrouting}, without any of the filled zones to better visualize the trace routing. For this, the recommended layout for the LM5175 \cite{lm7175data} was used as a base, while following the remaining guidelines imposed by the manufacturer.

\begin{figure}[H]
    \centering
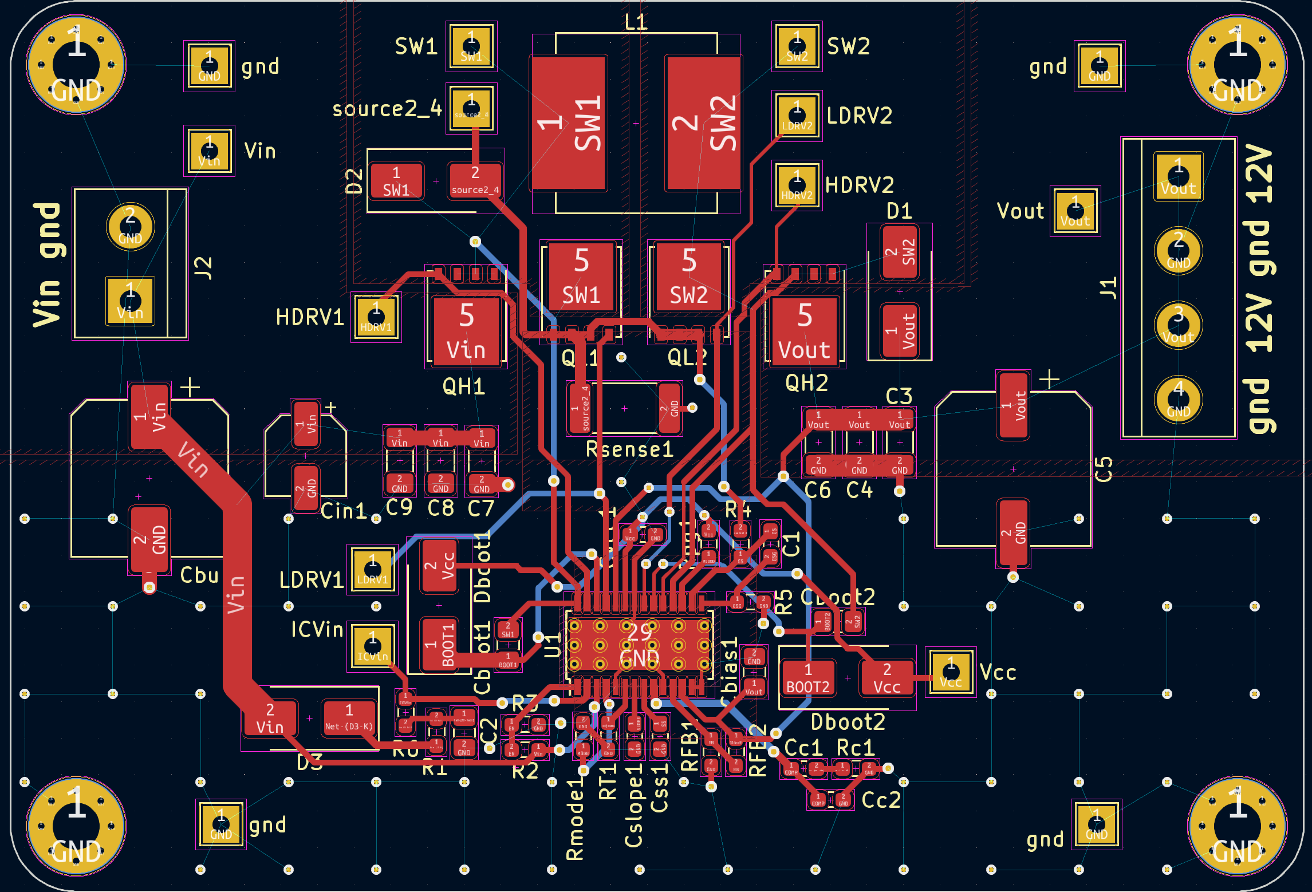
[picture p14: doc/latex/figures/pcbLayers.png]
    
    \caption{PCB routing}
    \label{fig:pcbrouting}
\end{figure}

\newpage

In figures \ref{fig:pcbfront} and \ref{fig:pcbback}, 3D renders of the populated boards can be seen, while figure \ref{fig:assembledBoard} shows the final board fully assembled.

\begin{figure}[H]
    \centering
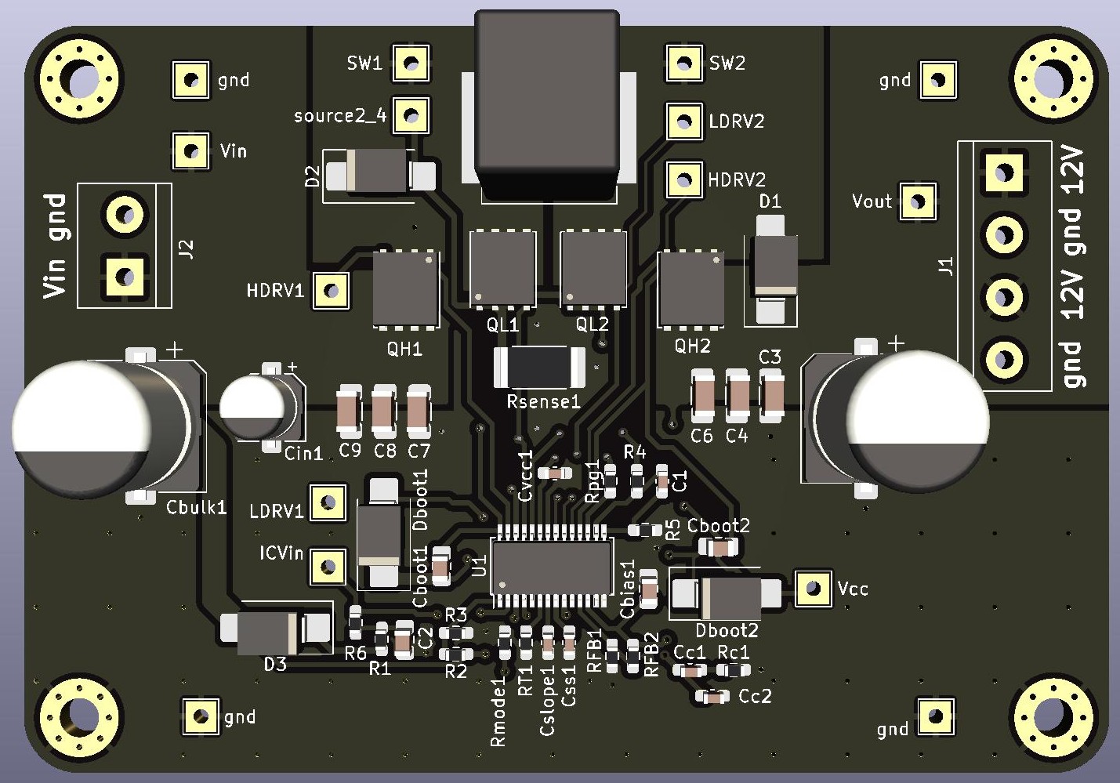
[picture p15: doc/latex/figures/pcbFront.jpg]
    
    \caption{Front of the PCB - 3D render}
    \label{fig:pcbfront}
\end{figure}

\begin{figure}[H]
    \centering
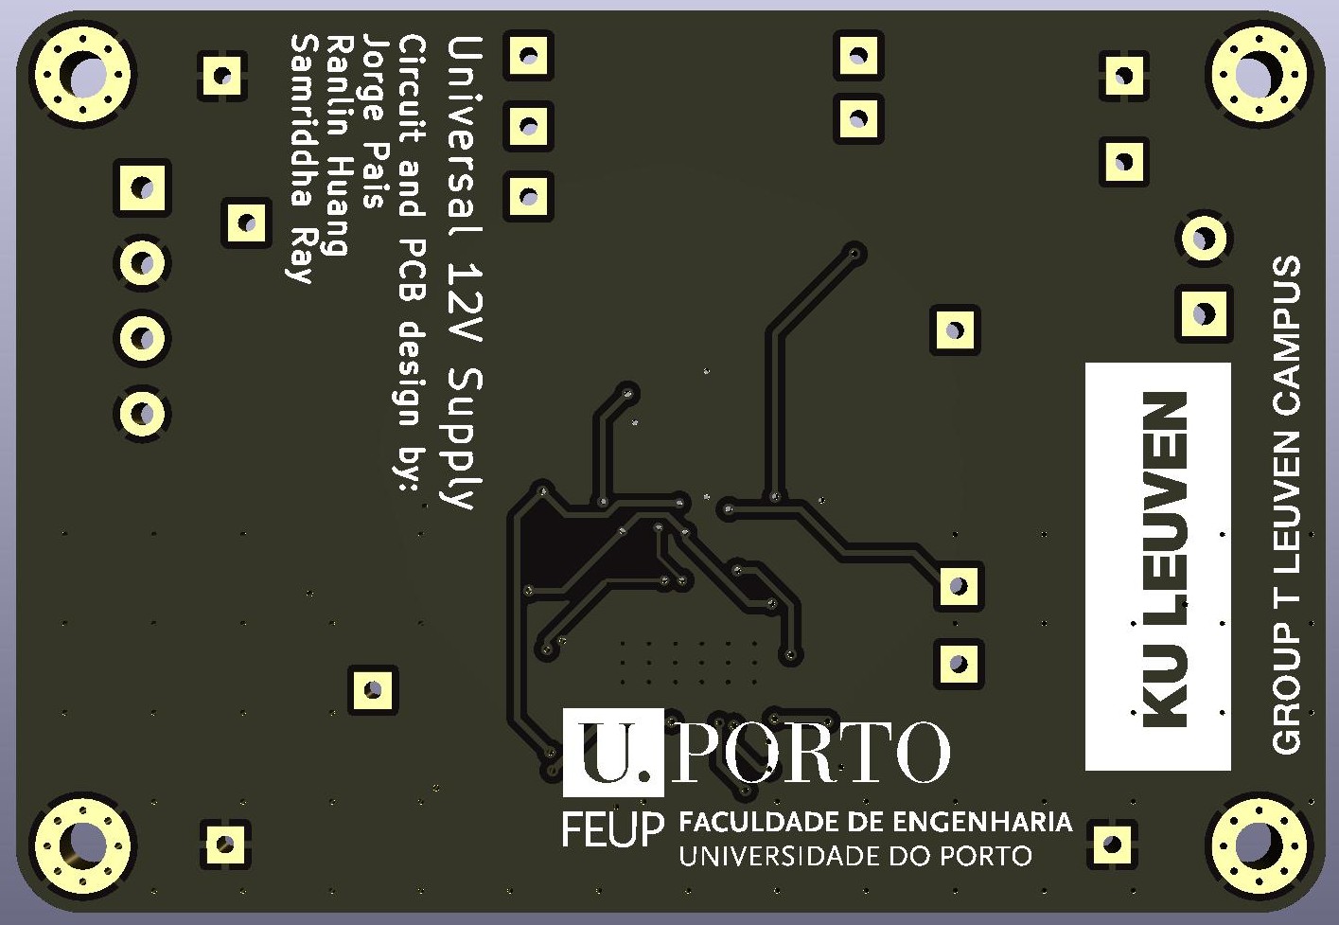
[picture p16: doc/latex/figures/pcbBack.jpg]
    
    \caption{Back of the PCB - 3D render}
    \label{fig:pcbback}
\end{figure}

Building the board was a matter of first laying solder paste across all SMD connections, carefully placing the components using tweezers and finally baking everything in the oven. The testpoints were then populated with small lugs which were hand soldered.

\begin{figure}[H]
    \centering
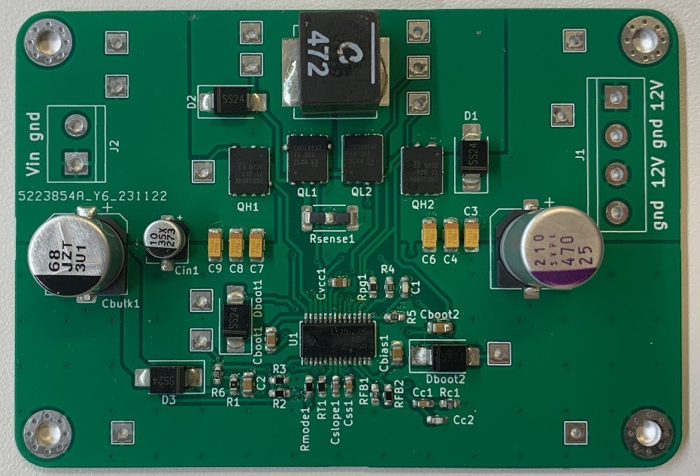
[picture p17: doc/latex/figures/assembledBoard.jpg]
    
    \caption{Final assembled board}
    \label{fig:assembledBoard}
\end{figure}

\section{Measurements}

\vfill \pagebreak
\printbibliography

\vfill \pagebreak

\begin{appendices}
    \includepdf[scale=1, fitpaper, angle=90]{./schematicSimple.pdf}
    \includepdf[scale=1, fitpaper, angle=90]{./BOM.pdf}
\end{appendices}

\end{document}

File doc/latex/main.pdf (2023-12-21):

## Power Electronics - 12V Universal Supply Design and Measurement Report

Jorge Pais
Ranlin Huang
Samriddha Ray

December 2023

1

### Contents

1 Introduction/Specification | 3
2 Design | 3
3 Measurements | 17

2

### 1 Introduction/Specification

Our project proposed for the power electronics course unit was the universal 12V power supply. The original specifications were as follows:

- Output voltage: 12V
- Input voltage : min. 5V; max. 18V
- Output Current: 1A

Considering these, the team attempted to overdimension the circuit in order to output more current (2A) and accept a higher range of input voltages (min. 5V and max. 24V).

### 2 Design

### 2.1 Circuit

As the basis for the design, the LM5175 buck-boost converter controller by Texas Instruments [1] was chosen. Since the design requires 2A of output current, a externally switched solution is a safer approach and as such the LM5175 presents a relatively modern design without many features such as I

2C that would not be utilized. Also the four switch buck-boost converter approach as some advantages over traditional single or dual switch topologies, since at any given time two of the MOSFETs are in either on or off state while the other commutate. This has the benefit that no diodes are needed, and thus lower forward voltage drops are present in both modes of operation.
An example circuit schematic for the circuit can be seen in figure 1. The circuit developed is based around this initial design and uses follows the dimensioning procedure that is described in the IC’s datasheet [1].

3


Figure 1: Simplified LM5175 Schematic

As for the final schematic, a simplified version without connectors and testpoints can be found at the end of this document as an appendix.

### 2.1.1 Switching Frequency

The LM5175’s switching frequency can be programmed between 100 and 600 kHz using a resistor from the RT/SYNC pin to ground. Higher values lead to higher overall efficiency but with added EMI and noise. The switching frequency was chosen to be 300kHz, as most examples featured in the datasheet used this value.

RT =

1/FSW − 190ns
116pF
= 27.4kΩ | (1)

### 2.1.2 Feedback Network

The output voltage of the circuit is set using a the feedback network between the output and the IC’s FB pin.

RF B2

RF B1

=

Vout − 0.8
0.8
= 14 | (2)

Choosing E48 series resistor values, a perfect ratio can be obtained:

RF B1 = 7.5kΩ; RF B2 = 105kΩ

4

### 2.1.3 Inductor Selection

The target inductance for Buck mode is given by the following formula:

Lbuck =

(VinMAX − Vout)Vout

0.4IoutMAXFSW VinMAX

= 25µH | (3)

And the target for boost mode is the following:

Lboost =

V

2
inMIN (Vout − VinMIN )

0.3IoutMAXFSW V

2
out
= 4.93µH | (4)

The maximum average inductor current is the following if we assume 90% efficiency:

ILmax =

VoutIoutMAX

0.9VinMIN

= 6.66A | (5)

Given this, the datasheet actually under specifies this component. A 4.7µH inductor can be utilized and as such, the XAL1010-472MED from Coilcraft [4] was chosen.
As for the peak inductor following through the inductor it is:

ILpeak = ILmax +

VinMIN (Vout − VinMIN )

2L1FswVout

≈ 6.66A | (6)

### 2.1.4 Output Capacitors

The value for the main output capacitor can be determined by the capacitive ripple voltage:

∆Vripple =

Iout(1 −

VinMIN
Vout

)

CoutFSW

(7)

And so, for a 10mV ripple from the capacitor, a value of 444.44µF is required. As such Cout = 470µF, which can be achieved with a small electrolytic capacitor. For this purpose Panasonic’s 25SPVK470M Polymer Aluminum capacitor was chosen, which has a maximum voltage rating of 25V and a ESR of 14mΩ.
Along side this, three smaller 15µF tantalum capacitors are placed in parallel, such as to minimize output ESR. So, the TPSA156K006R0700 from Kyocera Avx was chosen, each featuring an ESR of 7mΩ.
For the boost mode of operation the RMS current through the capacitor is given by:

ICoutRMS = Ioutr
Vout

Vin

− 1 | (8)

5

### 2.1.5 Input Capacitors

As for the input capacitors, in the buck operating region, they need to be able to supply high ripple current. It’s RMS current is given by the following equation, where the worst case scenario of D = 0.5 should be considered:

ICinrms = Ioutp
D(1 − D) = 1A | (9)

So in a similar fashion as for the output, a bulk electrolytic capacitor of 68µF was placed in parallel with several 15µF tantalum capacitors. The bulk capacitor chosen was the Panasonic EEHZT1J680P featuring a maximum voltage rating of 63V and a ESR of 25mΩ.

### 2.1.6 Current Limit

The circuit’s current limit is set by the Rsense resistor at the tail of the 4 mosfet switch bridge.

RsenseBUCK =

80mV

IoutMAX

= 40mΩ | (10)

RsenseBOOST =

120mV

ILpeak

= 18mΩ | (11)

This value is then set to Rsense = 18mΩ based on the boost mode operation. The power loss experienced by the Rsense is the following:

PsenseMAX =

120mV

Rsense 2
Rsense
1 −

VinMIN

Vout |
= 0.53W | (12)

Hence a 1W sense resistor is sufficient. As for the sense lines RCS and RCSG the values were chosen according to the example schematic provided on the datasheet: RCS = RCSG = 100Ω. A filter capacitor is also needed to attenuate the noise that can occur in these lines due to the large amounts of current passing through Rsense, as such a 47pF capacitor is utilized as a part of a differential mode filter in the CS and CSG pins to the LM5175.

### 2.1.7 MOSFETs

The LM5175 features four built-in N-channel MOSFET gate drivers. In buck operation, QL1 and QH1 are switched by the IC’s PWM controller while QH2 is continuously on and QL2 off. As for boost operation, QL2 and QH2 are switching while QH1 remains continuously on and QL2 is off. For the QH1 and QL2 MOSFETs on the input side, these need to withstand the maximum input voltage of the circuit, plus the possible voltage transient spikes. Considering the extended specifications, this value comes to VDSmax ≥ 24 + 20V . As for the output, transistors QH2 and QL2 should be rated for 12V plus the transient spikes.

6

When choosing a MOSFET for this circuit, it is also important to consider the rise/fall time and gate charges of the transistor, in order to minimize switching time and thus minimize switching loss. Also, the drain-to-source on-resistance should be minimal in order to lower the conduction losses. Considering these requirements, the MOSFET chosen for the 4 switches was the Texas Instruments’ CSD18532Q5B n-channel MOSFET [2], claiming to feature maximum Vgs of 60V and ultra-low gate charges.

### 2.1.8 Frequency Compensation

At the maximum load of 2A, output resistance is Rout = Vout/IoutMAX6Ω

fp1(boost) =

2

2πRoutCout

= 112Hz | (13)

fz1 =

1

2πResrCout

= 226Hz | (14)

The boost power stage RHP zero location is given by:

fRHP =

Rout(1 − Dmax)

2

2πL1

= 22.57kHz | (15)

Where Dmax is the maximum duty cycle at the minimum Vin: D = 1 −

Vi
Vo

= 0.667

fp1(buck) =

1

2πRoutCout

= 56.4379 | (16)

From these, it is clear that the RHP zero is the main factor limiting the achievable bandwidth.

fbw =

fRHP
3
= 7.52kHz | (17)

The compensation zero can be placed at 1.5 times the boost frequency pole.

fzc = 1.5fp1(boost) = 168Hz | (18)

Then the values for Rc1, Cc1 and Cc2 can be figured out through the following expressions:

Rc1 =

2πfbw

gmEA

RF B1 + RF B2

RF B1

AcsRsenseCout

1 − Dmax

= 68656Ω ≈ 68kΩ (19)

Cc1 =

1

2πfzcRc1

= 13.79nF ≈ 13nF | (20)

Cc2 =

1
2π5fbwRc1
= 61.65pF ≈ 62pF | (21)

7

### 2.1.9 Boilerplate Circuitry

In order to turn-on the IC, an appropriate voltage divider has to be built around the Enable/UVLO pin of the LM5175, which also functions as an undervoltage lockout, providing hysteresis between the turn-on and turn-off voltages. Using the following equation, the E96 values for the resistors can be calculated:
(

VUV = Ven
1 + RUV 1
RUV 2
− RUV 2Ien

RUV 1 = 59kΩ; RUV 1 = 249kΩ

(22)

The LM5175 also features what is called soft start, which charges an external capacitor whenever the converter is powered up, replacing the internal reference voltage for the feedback in the error amplifier. Once fully charged, the internal error amplifier is then referenced to Vref again.
A 20ms soft-start should be plenty for this circuit:
(
Iss = 5µA

Css =

tssIss
Vref

= 125nF ≈ 120nF

(23)

Apart from the frequency compensation dimensioned previously, slope compensation is also an important step in the design of any current-mode controlled converters in order to avoid oscillations. For the case of the LM5175 it should be dimensioned as such:

Cslope = gmslope

L1

RsenseAcs

= 100pF | (24)

Finally, the bootstrap capacitors and diodes also have to be chosen in order for the integrated MOSFET drivers to function as intended. For this purpose, 100nF ceramic caps were chosen. Also the SS24 Schottky Barrier Rectifier by Multicomp Pro was decided upon for the diodes due to it’s 2A forward current and 40V peak reverse voltage [3]. It doesn’t matter all that much as long as it’s a schottky, but this diode was chosen also because it could withstand the possible peak voltages from the MOSFET bridge, and reusing it throughout the circuit reduces the final BOM.

### 2.2 Power Losses & Efficiency

### 2.2.1 MOSFETs

In the buck mode of operation, the conduction and switching losses are given by the following formulas [1]:

8

Pcond(QH1) =

Vout
Vin

I

2
outRDSon

PSW(QH1) =

1
2

VinIout(tr + tf )FSW

Pcond(QL1) =

1 −

Vout

Vin
I

2
outRDSon

Pcond(QH2) = I

2
outRDSon

(25)

As for when the converter is operating in boost mode:

Pcond(QH1) =

Vout
Vin

Iout2
RDSon

Pcond(QL2) =

1 −

Vout

Vin Vout

Vin

Iout2
RDSon

PSW(QL2) =

1
2

Vout
Vout
Vin

Iout
(tr + tf )FSW

Pcond(QH2) =

Vin

Vout
Iout

Vout

Vin 2
RDSon

(26)

If we plug some of the datasheet specifications into the power loss equations, along with the worst case values for Vin and Iout then the results on table 1 are obtained. It should be taken into account that the actual rise/fall switching times have to be determined empirically in the lab, so the values used consider a much higher current than what our circuit consumes.

Buck | Boost
Pcond(QH1) PSW(QH1) Pcond(QL1) Pcond(QH2) | 8.6mW 74.2mW 8.6mW 17.2mW | Pcond(QH1) Pcond(QL2) PSW(QL2) Pcond(QH2) | 99.1mW 57.8mW 59.4mW 41.3mW

Table 1: Maximum MOSFET Power Losses

From these it is also to obtain an idea of the thermal performance of these MOSFETs (table 2), which even at 2A barely heat up indicating very strong efficiency. This is mostly due to the transistors chosen having both very low gate charges and low RDSon.

Transistor | Temperature Rise ∆T(°C)
QH1Buck QL1Buck QH2Buck QH1Boost QL2Boost QH2Boost | 4.14 0.43 0.86 4.96 5.86 2.07

Table 2: Junction-ambient temperature rise

9

Figures 2 and 3 show how these losses are related to both the output current and varying input voltage.


Figure 2: Buck mode MOSFET losses


Figure 3: Boost mode MOSFET losses

### 2.2.2 Inductor

Taking the formula for the RMS current through the inductor (with the previous assumption of 90% efficiency, which certainly is a gross approximation especially when considering lower output currents), an estimate for dissipated power can be obtained if we consider the inductor’s wire resistance Rw = 5.70mΩ [4]:

Pinductor = I

2
LRMSRw =
VoutIout

0.9Vin 2
Rw | (27)

10

This gives a maximum power loss when the current is maximum and the input voltage is minimum, with a value of PLmax = 162mW. In figure 4 we can observe the power loss in relation to the output current that is drawn from the converter, for varying input voltages.


Figure 4: Inductor power losses

### 2.2.3 Capacitor Losses

During the boost mode of operation the output capacitors are responsible for conducting high ripple current. Using formula 8 for the output current, capacitor buck-mode power losses can be estimated. The total ESR for the output capacitances is ESR = 2.0mΩ.

PCout = I

2
CrmsESR = I

2

out
Vout

Vin

− 1

ESR | (28)

Figure 5 shows these losses as a function of the output current and the input voltage. It is possible to see that the biggest losses are when the input voltage is minimum where PCout = 11mW.

11


Figure 5: Output capacitor power losses

As for the input capacitances, the formula for the RMS current in equation 9 can be utilized to figure out the power losses. The total ESR for the input capacitors is 2.13mΩ.

PCin = I

2
CrmsESR = I

2
outD(1 − D)ESR | (29)

Using this, figure 6 displays a plot of the power losses in respect to the output current. The maximum power loss is then obtained when the duty cycle is D = 0.5, where PCin = 2.1mW


Figure 6: Input capacitor power losses

### 2.2.4 Sense resistor

A formula for determining the power loss in Rsense was already shown in equation 12, but only for the boost mode. In this case the power loss was the following, in the worst case scenario:

12

PsenseBoost = 530mW

For the buck mode, the formula is pretty much the same, only that the duty cycle is different and now we use the buck current limit threshold VCS(BUCK) = 80mV for the calculation.

PsenseBuck =

80mV

Rsense 2
Rsense
Vout

VinMAX
= 178mW | (30)

### 2.2.5 Total Losses

From the previous analysis, the total losses for each mode of operation can be calculated. Firstly the buck mode losses can be seen in figure 7 which consider the worst case of Vin = 24V.


Figure 7: Total buck mode losses

Figure 8 shows the same, but for the boost mode of operation, in the worst case when the input voltage is 5V.

13


Figure 8: Total boost mode losses

### 2.2.6 Efficiency

From the total losses, it is then possible to see what the theoretical efficiency of the converter is. Figure 9 shows the worst case scenario efficiency for both the Boost and Buck modes (Vin = 5V and Vin = 24V respectively), as a function of output current.


Figure 9: Buck and Boost efficiency

### 2.3 Board

The board was designed utilizing KiCad 7 for both the schematic capture and PCB layout. Some of the specifications for the board were based on the project limitations and the constraints posed by JLCPCB manufacturing. These were was follows:

- 2 layers, bottom GND plane

14

- SMD only, except for connectors/testpoints
- Min. copper clearence: 0.2mm
- Min. track width: 0.2mm
- Min. annular width: 0.13mm
- Min. via diameter: 0.7mm
- Min. copper to hole clearence: 0.25mm
- Min. through-hole diameter: 0.3mm
- Min. hole-to-hole clearence: 0.254mm

Considering these, a relatively simple and compact layout was achieved, whose routing can be seen in figure 10, without any of the filled zones to better visualize the trace routing. For this, the recommended layout for the LM5175 [1] was used as a base, while following the remaining guidelines imposed by the manufacturer.

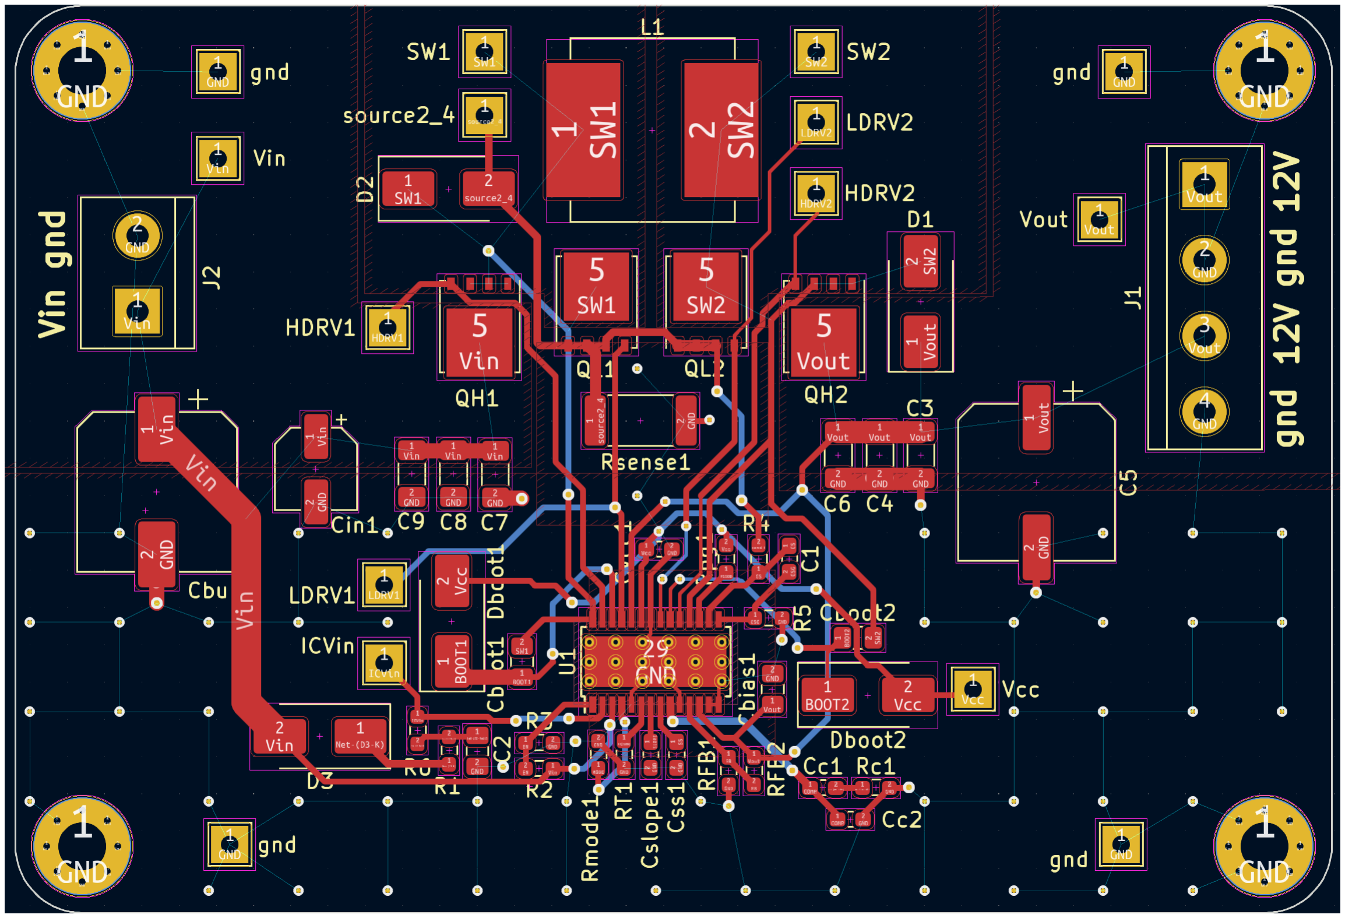
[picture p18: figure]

Figure 10: PCB routing

15

In figures 11 and 12, 3D renders of the populated boards can be seen, while figure 13 shows the final board fully assembled.


Figure 11: Front of the PCB - 3D render


Figure 12: Back of the PCB - 3D render

Building the board was a matter of first laying solder paste across all

16

SMD connections, carefully placing the components using tweezers and finally baking everything in the oven. The testpoints were then populated with small lugs which were hand soldered.


Figure 13: Final assembled board

### 3 Measurements

17

### References

[1] 42-v wide vin synchronous 4-switch buck-boost controller, LM5174, Rev.
A, Texas Instruments, May 2016.

## [2] 60-v n-channel nexfet™ power mosfets, CSD18532Q5B, Rev. D, Texas

Instruments, Feb. 2018.
[3] Schottky rectifier, SS24+, V1.1, Multicomp Pro, Sep. 2019.
[4] Shielded power inductors, XAL1010, Doc. 804, Coilcraft, Jun. 2021.

18

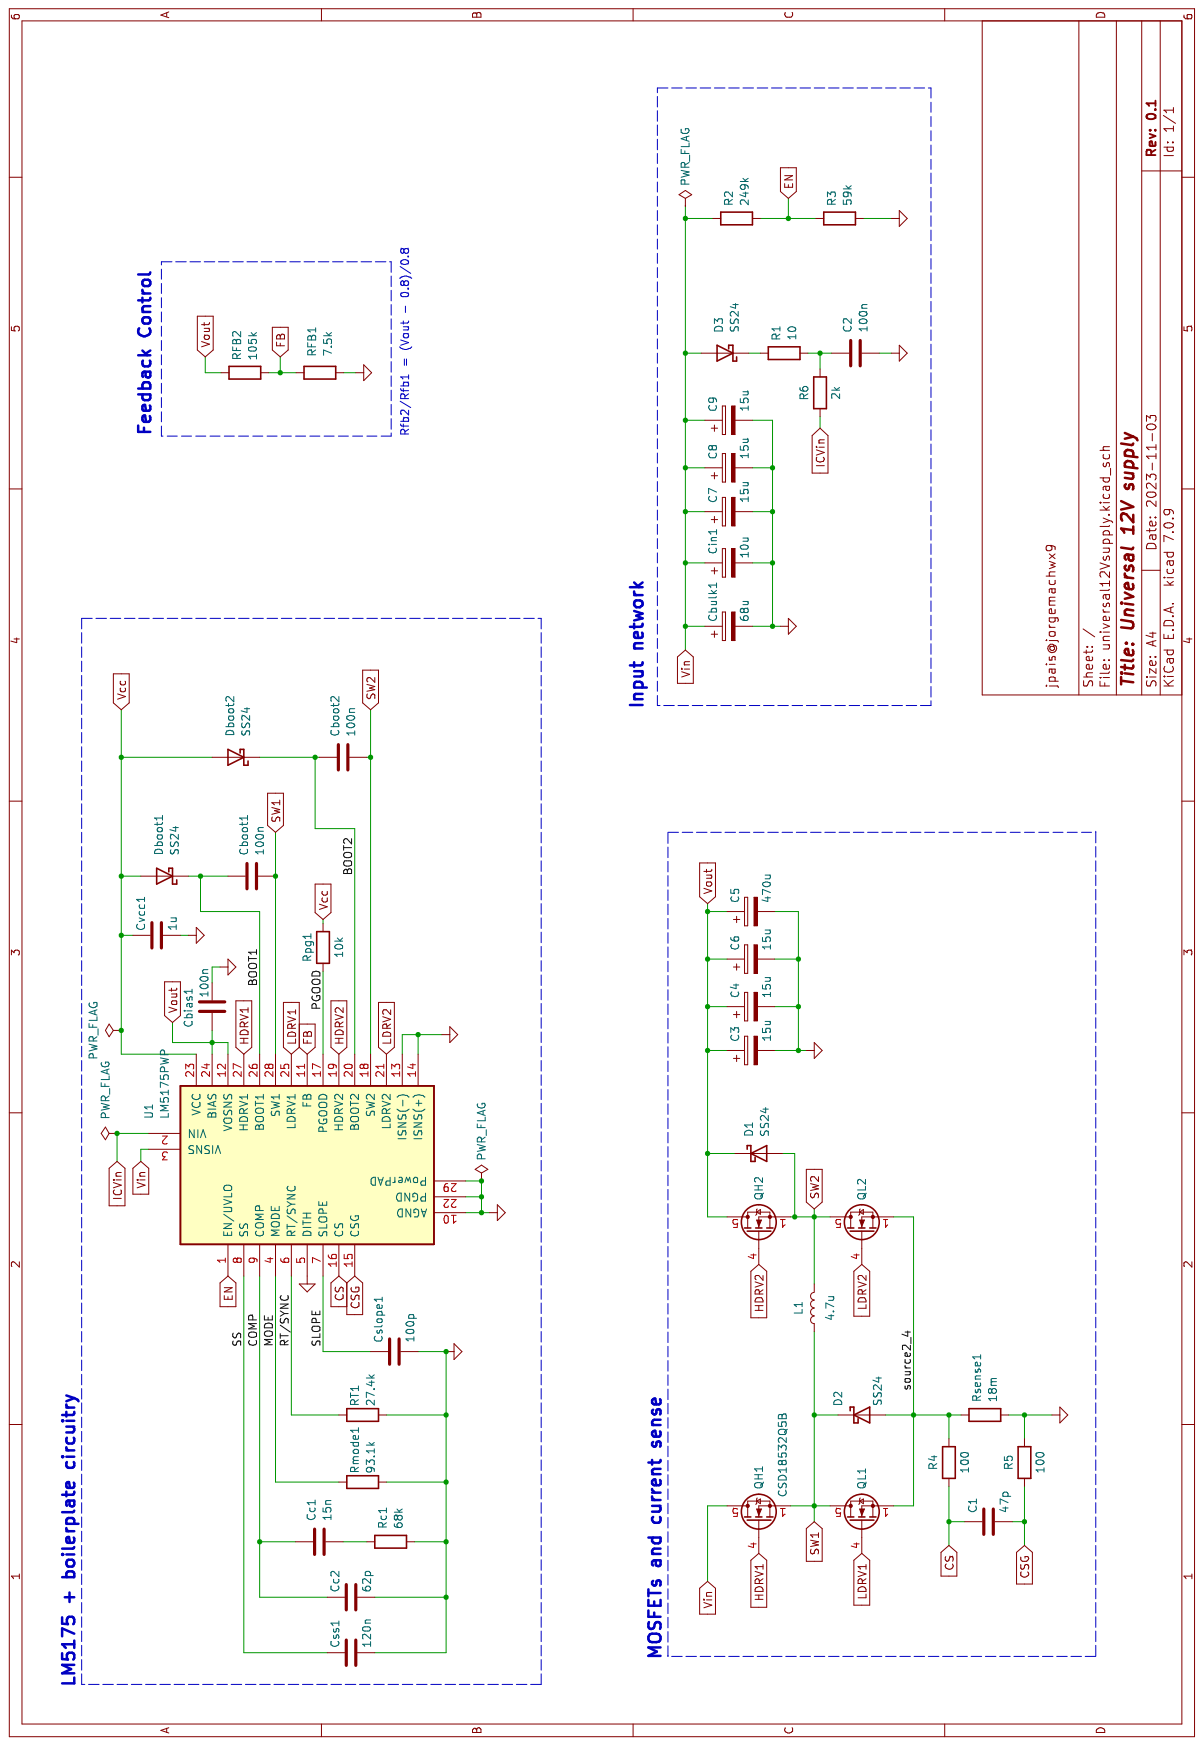
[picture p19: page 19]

Reference Value Footprint Datasheet Farnell Qty Farnell Order Code

C1 47p Capacitor_S~ https://be.farnell.com/en-BE/kemet/c0603c470f1gact 1 2820807

C2 100n Capacitor_S~ https://be.farnell.com/en-BE/kemet/c0805x104j5rac33 1 2666904

C3, C4, C6, C7, C8, C9 15u Capacitor_S~ https://be.farnell.com/en-BE/avx/tpsa156k006r0700/c 6 1658485

C5 470u Capacitor_S~ https://be.farnell.com/en-BE/panasonic/25svpk470m/ 1 2759084

Cbias1 100n Capacitor_S~ https://be.farnell.com/en-BE/kemet/c0805x104j5rac33 1 2666904

Cboot1, Cboot2 100n Capacitor_S~ https://be.farnell.com/en-BE/kemet/c0805x104j5rac33 2 2666904

Cbulk1 68u Capacitor_S~ https://be.farnell.com/en-BE/panasonic/eehzt1j680p/c 1 3584428

Cc1 15n Capacitor_S~ https://be.farnell.com/en-BE/multicomp/mc0603b153 1 2320805

Cc2 62p Capacitor_S~ https://be.farnell.com/en-BE/kemet/c0603c620j5gactu 1 1865482

Cin1 10u Capacitor_S~ https://be.farnell.com/en-BE/kemet/exv106m035a9da 1 2069187

Cslope1 100p Capacitor_S~ https://be.farnell.com/en-BE/kemet/c0603x101f5gaca 1 2904893

Cvcc1 1u Capacitor https://be.farnell.com/en-BE/kemet/c0805c105j8ractu 1 2773210

Css1 120n Capacitor_S~ https://be.farnell.com/en-BE/kemet/c0603c124k8ract 1 2821085

D1-D3 SS24 Diode_SMD~ https://be.farnell.com/en-BE/multicomp/ss24/schottk 3 2675138

Dboot1, Dboot2 SS24 Diode_SMD~ https://be.farnell.com/en-BE/multicomp/ss24/schottk 2 2675138

L1 4.7u Inductor_S~ https://be.farnell.com/en-BE/coilcraft/xal1010-472me 1 2289017

QH1, QH2 CSD18532Q5B Package_TOhttp://www.ti.com/ https://be.farnell.com/en-BE/texas-instruments/csd18 2 3009663

QL1, QL2 CSD18532Q5B Package_TOhttp://www.ti.com/ https://be.farnell.com/en-BE/texas-instruments/csd18 2 3009663

R1 10R Resistor_SM~ https://be.farnell.com/en-BE/rohm/ktr03ezpf10r0/res 1 2919225

R2 249k Resistor_SM~ https://be.farnell.com/en-BE/panasonic/erjpa3f2493v/ 1 2561907

R3 59k Resistor_SM~ https://be.farnell.com/en-BE/panasonic/erjpa3f5902v/ 1 2562106

R4, R5 100R Resistor_SM~ https://be.farnell.com/en-BE/vishay/rca0603100rfkea/ 2 2616583

R6 2k Resistor_SM~ https://be.farnell.com/en-BE/panasonic/era3arw202v/ 1 2797306

Rc1 68k Resistor_SM~ https://be.farnell.com/en-BE/te-connectivity/crgcq060 1 2861483

RFB1 7.5k Resistor_SM~ https://be.farnell.com/en-BE/multicomp-pro/mcsr06x7 1 2074303

RFB2 105k Resistor_SM~ https://be.farnell.com/en-BE/panasonic/erjpa3f1053v/ 1 2561729

Rmode1 93.1k Resistor_SM~ https://be.farnell.com/en-BE/panasonic/erjpa3f9312v/ 1 2562207

Rpg1 10k Resistor_SM~ https://be.farnell.com/en-BE/vishay/rca060310k0fkea/ 1 2616584

Rsense1 18m Resistor_SM~ https://be.farnell.com/en-BE/multicomp/mchvr12ftft1 1 2826912

RT1 27.4k Resistor_SM~ https://be.farnell.com/en-BE/panasonic/erjpa3f2742v/ 1 2561929

U1 LM5175PWP Package_SOhttp://www.ti.com/ https://be.farnell.com/en-BE/texas-instruments/lm517 1 3008670

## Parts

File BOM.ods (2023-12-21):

Reference | Value | Footprint | Datasheet | Farnell | Qty | Farnell Order Code
C1 | 47p | Capacitor_SMD:C_0603_1608Metric_Pad1.08x0.95mm_HandSolder | ~ | https://be.farnell.com/en-BE/kemet/c0603c470f1gactu/cap-47pf-100v-1-c0g-np0-0603/dp/2820807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 | 1 | 2820807
C2 | 100n | Capacitor_SMD:C_0805_2012Metric_Pad1.18x1.45mm_HandSolder | ~ | https://be.farnell.com/en-BE/kemet/c0805x104j5rac3316/cap-0-1-f-50v-5-x7r-0805/dp/2666904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 | 1 | 2666904
C3, C4, C6, C7, C8, C9 | 15u | Capacitor_SMD:C_1206_3216Metric_Pad1.33x1.80mm_HandSolder | ~ | https://be.farnell.com/en-BE/avx/tpsa156k006r0700/cap-15-f-6-3v-10-1206-smd/dp/1658485?st=15u%20smd%20cap | 6 | 1658485
C5 | 470u | Capacitor_SMD:CP_Elec_10x12.6 | ~ | https://be.farnell.com/en-BE/panasonic/25svpk470m/cap-470-f-25v/dp/2759084?st=470u%20smd%20cap | 1 | 2759084
Cbias1 | 100n | Capacitor_SMD:C_0805_2012Metric_Pad1.18x1.45mm_HandSolder | ~ | https://be.farnell.com/en-BE/kemet/c0805x104j5rac3316/cap-0-1-f-50v-5-x7r-0805/dp/2666904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 | 1 | 2666904
Cboot1, Cboot2 | 100n | Capacitor_SMD:C_0805_2012Metric_Pad1.18x1.45mm_HandSolder | ~ | https://be.farnell.com/en-BE/kemet/c0805x104j5rac3316/cap-0-1-f-50v-5-x7r-0805/dp/2666904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 | 2 | 2666904
Cbulk1 | 68u | Capacitor_SMD:CP_Elec_10x10.5 | ~ | https://be.farnell.com/en-BE/panasonic/eehzt1j680p/cap-68uf-63v-alu-elec-hybrid-smd/dp/3584428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 | 1 | 3584428
Cc1 | 15n | Capacitor_SMD:C_0603_1608Metric_Pad1.08x0.95mm_HandSolder | ~ | https://be.farnell.com/en-BE/multicomp/mc0603b153j500ct/cap-0-015-f-50v-5-x7r-0603/dp/2320805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 | 1 | 2320805
Cc2 | 62p | Capacitor_SMD:C_0603_1608Metric_Pad1.08x0.95mm_HandSolder | ~ | https://be.farnell.com/en-BE/kemet/c0603c620j5gactu/cap-62pf-50v-5-c0g-np0-0603/dp/1865482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 | 1 | 1865482
Cin1 | 10u | Capacitor_SMD:CP_Elec_5x5.4 | ~ | https://be.farnell.com/en-BE/kemet/exv106m035a9daa/cap-10-f-35v-radial-smd/dp/2069187?st=10u%20smd%20cap | 1 | 2069187
Cslope1 | 100p | Capacitor_SMD:C_0603_1608Metric_Pad1.08x0.95mm_HandSolder | ~ | https://be.farnell.com/en-BE/kemet/c0603x101f5gacauto/cap-100pf-50v-1-c0g-np0-0603/dp/2904893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 | 1 | 2904893
Cvcc1 | 1u | Capacitor |  | https://be.farnell.com/en-BE/kemet/c0805c105j8ractu/cap-1-f-10v-5-x7r-0805/dp/2773210?st=1u%20smd%20cap%200805 | 1 | 2773210
Css1 | 120n | Capacitor_SMD:C_0603_1608Metric_Pad1.08x0.95mm_HandSolder | ~ | https://be.farnell.com/en-BE/kemet/c0603c124k8ractu/cap-0-12-f-10v-10-x7r-0603/dp/2821085?st=120n%20smd%20cap | 1 | 2821085
D1-D3 | SS24 | Diode_SMD:D_SMB_Handsoldering | ~ | https://be.farnell.com/en-BE/multicomp/ss24/schottky-rectifier-2a-40v-do-214aa/dp/2675138?MER=sy-me-pd-mi-alte | 3 | 2675138
Dboot1, Dboot2 | SS24 | Diode_SMD:D_SMB_Handsoldering | ~ | https://be.farnell.com/en-BE/multicomp/ss24/schottky-rectifier-2a-40v-do-214aa/dp/2675138?MER=sy-me-pd-mi-alte | 2 | 2675138
L1 | 4.7u | Inductor_SMD:L_Coilcraft_XAL1010-XXX | ~ | https://be.farnell.com/en-BE/coilcraft/xal1010-472med/inductor-4-7uh-24a-20-pwr-19mhz/dp/2289017 | 1 | 2289017
QH1, QH2 | CSD18532Q5B | Package_TO_SOT_SMD:TDSON-8-1 | http://www.ti.com/lit/gpn/csd18532q5b | https://be.farnell.com/en-BE/texas-instruments/csd18532q5b/mosfet-n-ch-60v-100a-vson-8/dp/3009663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 | 2 | 3009663
QL1, QL2 | CSD18532Q5B | Package_TO_SOT_SMD:TDSON-8-1 | http://www.ti.com/lit/gpn/csd18532q5b | https://be.farnell.com/en-BE/texas-instruments/csd18532q5b/mosfet-n-ch-60v-100a-vson-8/dp/3009663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 | 2 | 3009663
R1 | 10R | Resistor_SMD:R_0603_1608Metric_Pad0.98x0.95mm_HandSolder | ~ | https://be.farnell.com/en-BE/rohm/ktr03ezpf10r0/res-10r-1-0-1w-0603-thick-film/dp/2919225?st=10r+resistor+0603 | 1 | 2919225
R2 | 249k | Resistor_SMD:R_0603_1608Metric_Pad0.98x0.95mm_HandSolder | ~ | https://be.farnell.com/en-BE/panasonic/erjpa3f2493v/res-249k-1-thick-film/dp/2561907?st=249k%20resistor+0603 | 1 | 2561907
R3 | 59k | Resistor_SMD:R_0603_1608Metric_Pad0.98x0.95mm_HandSolder | ~ | https://be.farnell.com/en-BE/panasonic/erjpa3f5902v/res-59k-1-thick-film/dp/2562106?st=59k%20resistor%200603 | 1 | 2562106
R4, R5 | 100R | Resistor_SMD:R_0603_1608Metric_Pad0.98x0.95mm_HandSolder | ~ | https://be.farnell.com/en-BE/vishay/rca0603100rfkea/res-100r-1-0603-thick-film/dp/2616583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 | 2 | 2616583
R6 | 2k | Resistor_SMD:R_0603_1608Metric_Pad0.98x0.95mm_HandSolder | ~ | https://be.farnell.com/en-BE/panasonic/era3arw202v/res-2k-0-05-metal-film/dp/2797306?st=2k%200603%20resistor | 1 | 2797306
Rc1 | 68k | Resistor_SMD:R_0603_1608Metric_Pad0.98x0.95mm_HandSolder | ~ | https://be.farnell.com/en-BE/te-connectivity/crgcq0603f68k/res-68k-1-0603-thick-film/dp/2861483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 | 1 | 2861483
RFB1 | 7.5k | Resistor_SMD:R_0603_1608Metric_Pad0.98x0.95mm_HandSolder | ~ | https://be.farnell.com/en-BE/multicomp-pro/mcsr06x7501ftl/res-7k5-1-0-1w-0603-thick-film/dp/2074303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 | 1 | 2074303
RFB2 | 105k | Resistor_SMD:R_0603_1608Metric_Pad0.98x0.95mm_HandSolder | ~ | https://be.farnell.com/en-BE/panasonic/erjpa3f1053v/res-105k-1-thick-film/dp/2561729 | 1 | 2561729
Rmode1 | 93.1k | Resistor_SMD:R_0603_1608Metric_Pad0.98x0.95mm_HandSolder | ~ | https://be.farnell.com/en-BE/panasonic/erjpa3f9312v/res-93k1-1-thick-film/dp/2562207 | 1 | 2562207
Rpg1 | 10k | Resistor_SMD:R_0603_1608Metric_Pad0.98x0.95mm_HandSolder | ~ | https://be.farnell.com/en-BE/vishay/rca060310k0fkea/res-10k-1-0603-thick-film/dp/2616584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 | 1 | 2616584
Rsense1 | 18m | Resistor_SMD:R_2512_6332Metric_Pad1.40x3.35mm_HandSolder | ~ | https://be.farnell.com/en-BE/multicomp/mchvr12ftft1805/res-thick-film-18m-1-1w-2512/dp/2826912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 | 1 | 2826912
RT1 | 27.4k | Resistor_SMD:R_0603_1608Metric_Pad0.98x0.95mm_HandSolder | ~ | https://be.farnell.com/en-BE/panasonic/erjpa3f2742v/res-27k4-1-thick-film/dp/2561929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 | 1 | 2561929
U1 | LM5175PWP | Package_SO:HTSSOP-28-1EP_4.4x9.7mm_P0.65mm_EP3.4x9.5mm_ThermalVias | http://www.ti.com/lit/ds/symlink/lm5175.pdf | https://be.farnell.com/en-BE/texas-instruments/lm5175pwpt/dc-dc-ctrl-sync-buck-boost-htssop28/dp/3008670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 | 1 | 3008670

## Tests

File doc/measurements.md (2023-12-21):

# Power Electronics Project - Measurements

### Input Regulation ($Z_{out} = 200\Omega$)

Minimum input voltage is actually 7.8V, circuit was not able to make it to 5V even.

figures @ min and max voltage:
CH1 - SW1
CH2 - SW2

| $V_{in} (\text V)$  | $V_{out} (\text V)$ |
| - | - |
| 7.8 | 12.076 |
| 10.0 | 12.077 |
| 12.0 | 12.069 |
| 14.0 | 12.064 |
| 16.0 | 12.063 |
| 18.0 | 12.062 |
| 20.0 | 12.064 |
| 22.0 | 12.857 |
| 24.0 | 12.789 |

### Load regulation & Efficiency

| $Z_{load} (\Omega)$  | $V_{out} (\text V)$ | $I_{in} (\text A)$ |
| - | - | - |
| 200 | 12.062 | 0.13 |
| 100 | 12.077 | 0.17 |
| 50 | 12.078 | 0.25 |
| 24 | 12.063 | 0.41 |
| 12 | 12.064 | 0.75 |

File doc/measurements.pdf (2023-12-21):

## Power Electronics Project - Measurements

Input Regulation (Zout = 200Ω)

Minimum input voltage is actually 7.8V, circuit was not able to make it to 5V even.

figures @ min and max voltage: CH1 - SW1 CH2 - SW2

Vin(V) | Vout(V)
7.8 | 12.076
10.0 | 12.077
12.0 | 12.069
14.0 | 12.064
16.0 | 12.063
18.0 | 12.062
20.0 | 12.064
22.0 | 12.857
24.0 | 12.789

Load regulation & Efficiency

Zload(Ω) | Vout(V) | Iin(A)
200 | 12.062 | 0.13
100 | 12.077 | 0.17
50 | 12.078 | 0.25
24 | 12.063 | 0.41
12 | 12.064 | 0.75

1

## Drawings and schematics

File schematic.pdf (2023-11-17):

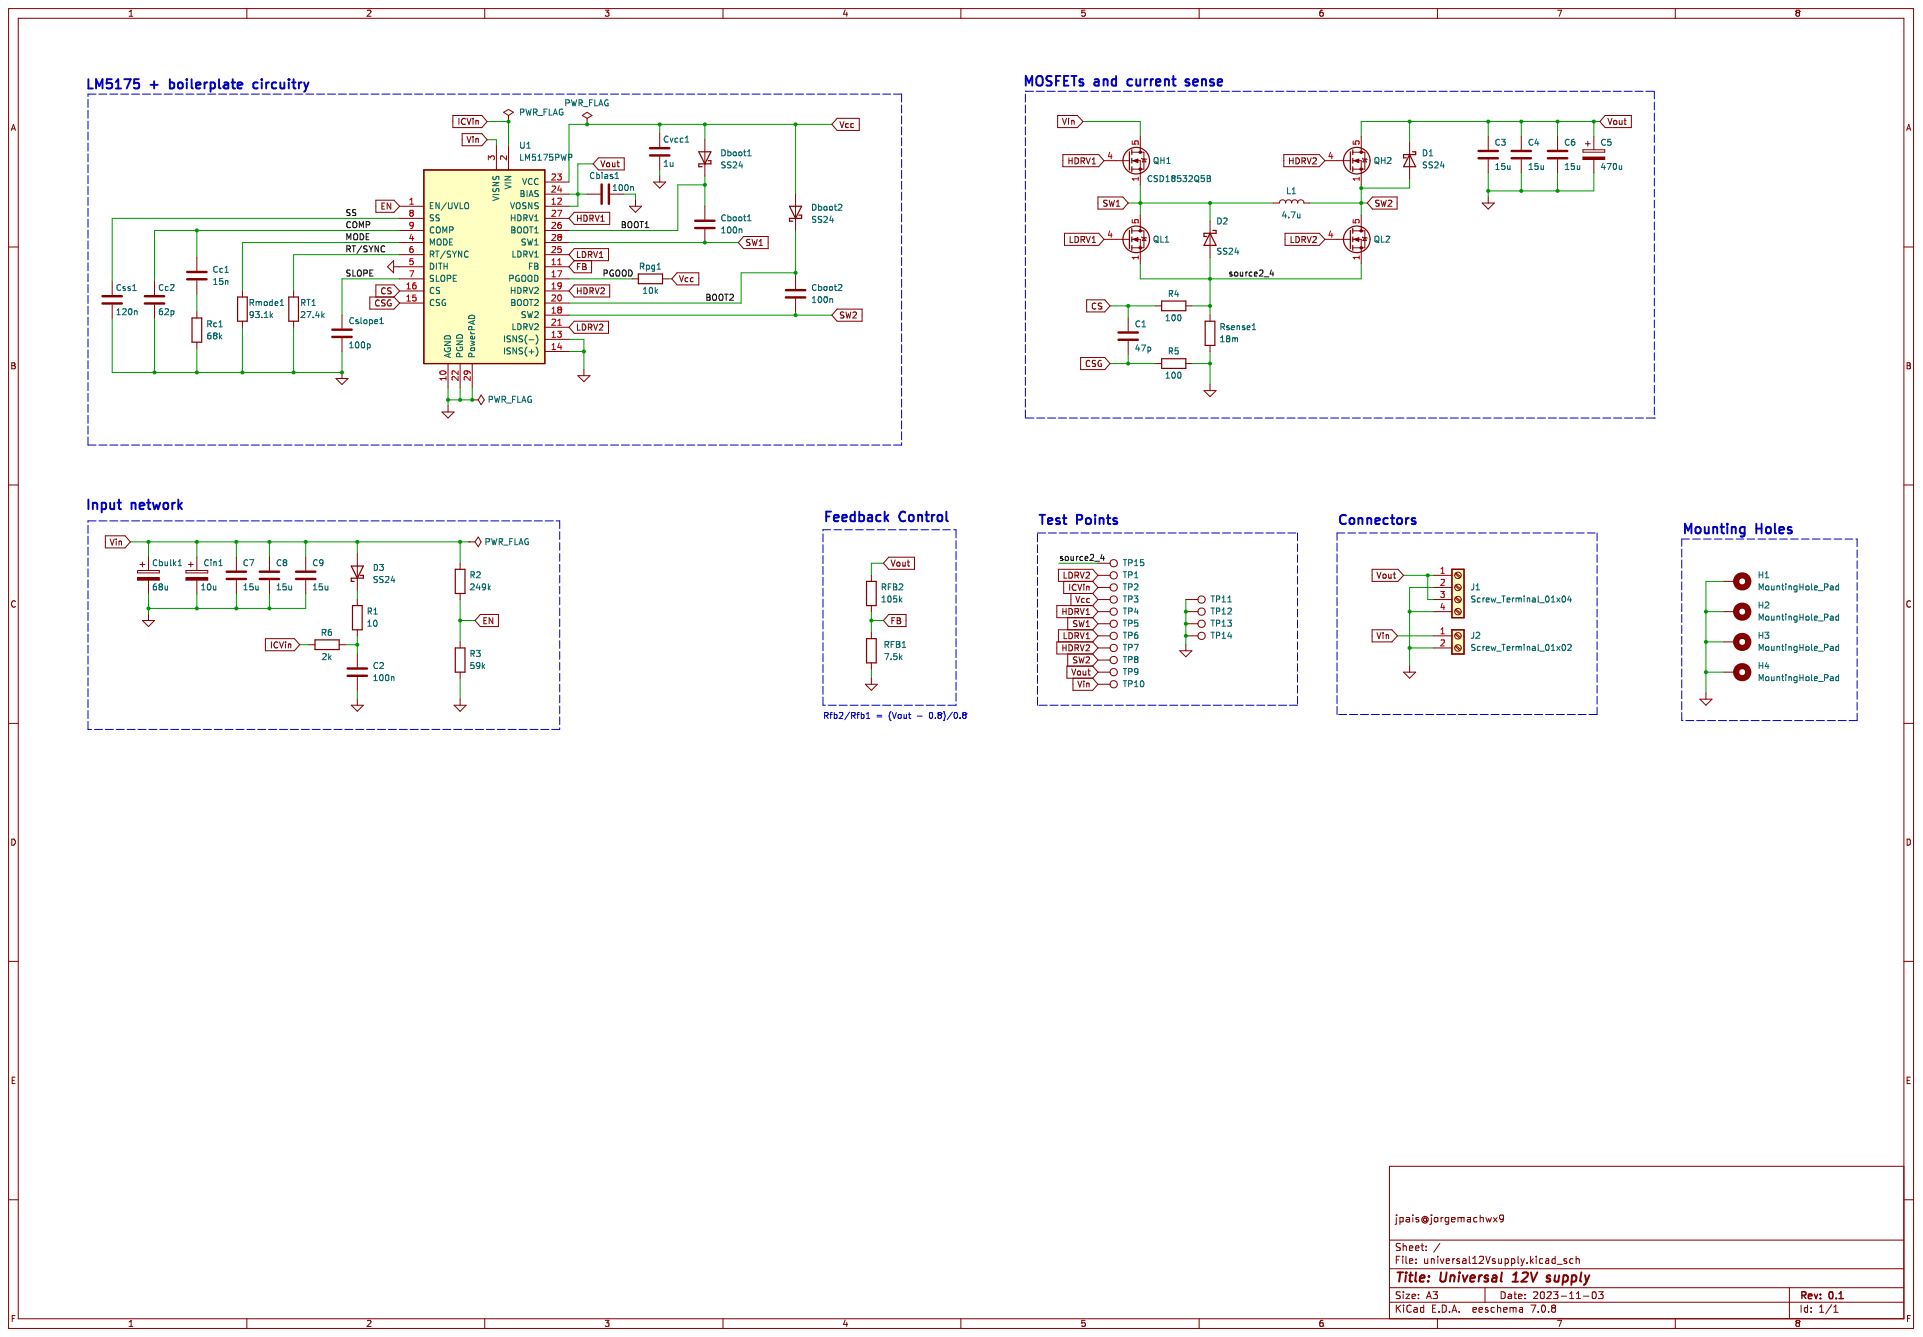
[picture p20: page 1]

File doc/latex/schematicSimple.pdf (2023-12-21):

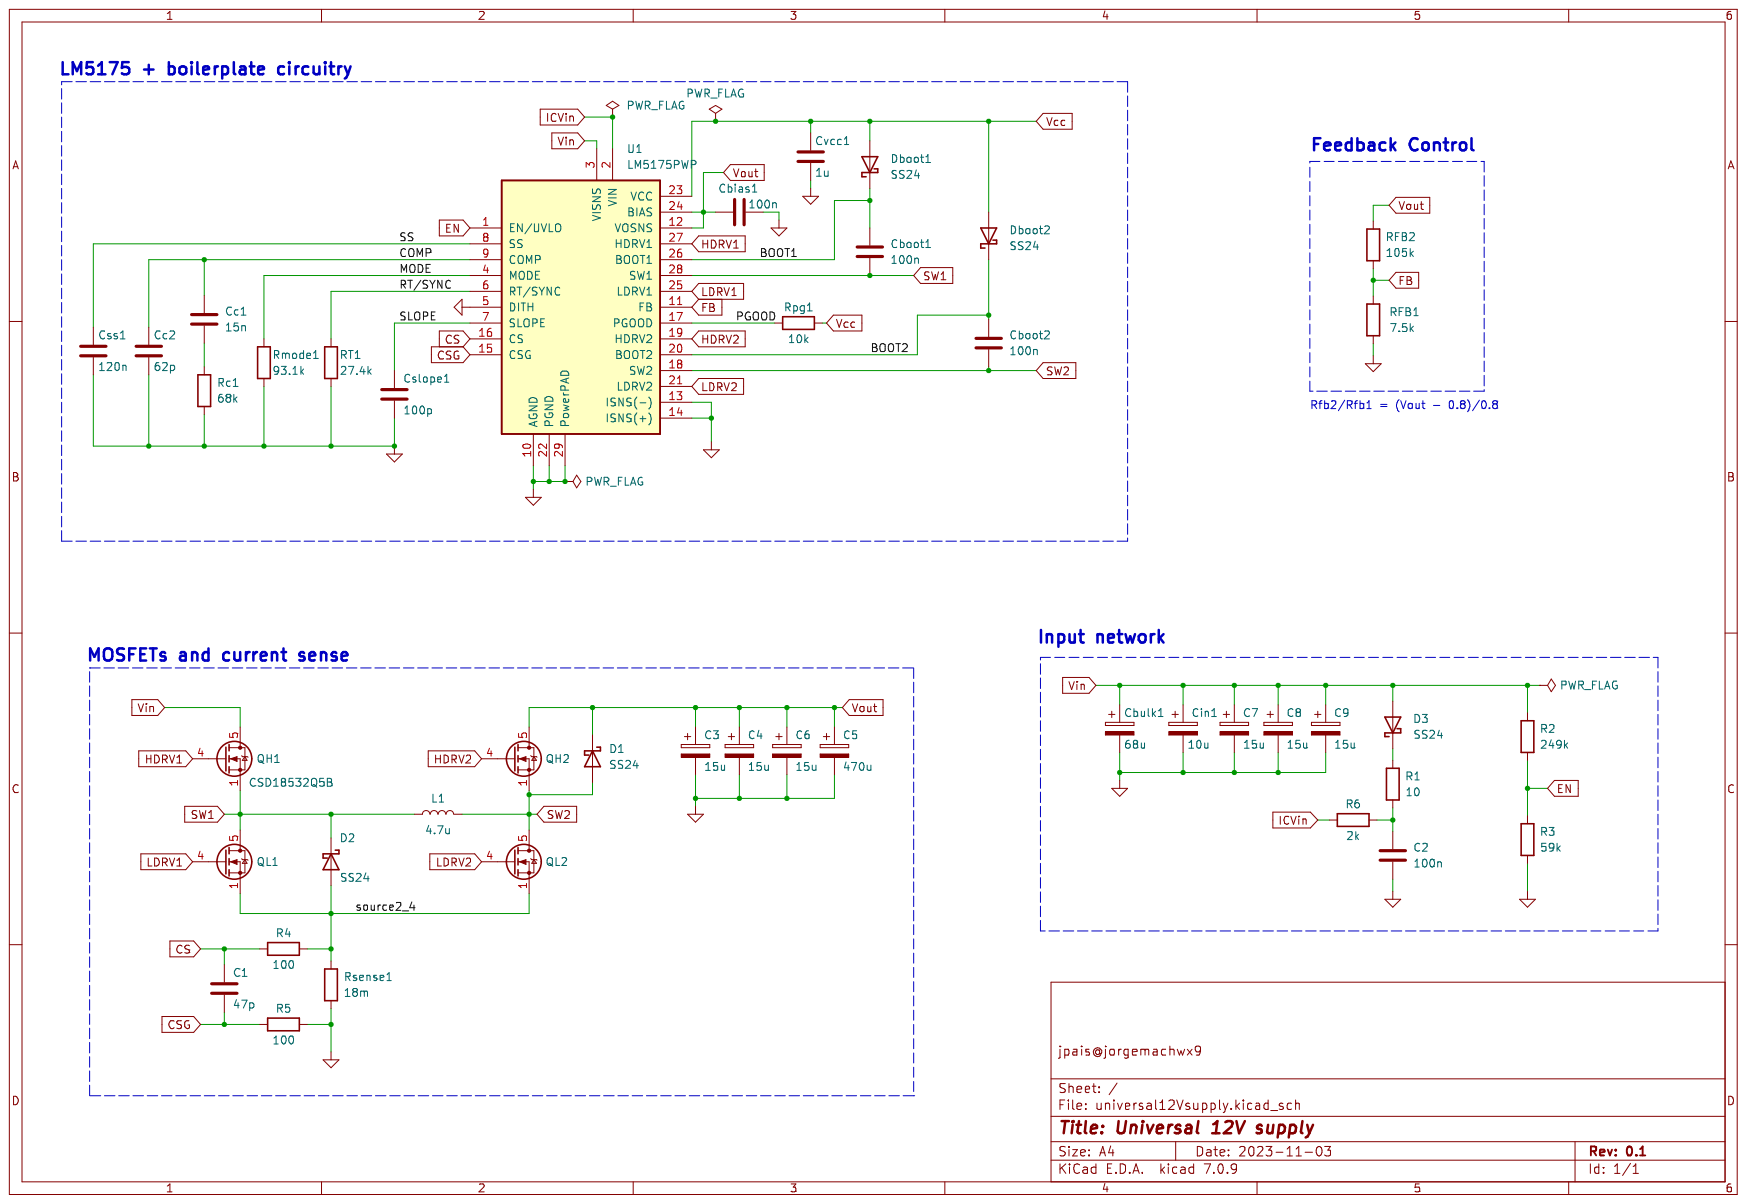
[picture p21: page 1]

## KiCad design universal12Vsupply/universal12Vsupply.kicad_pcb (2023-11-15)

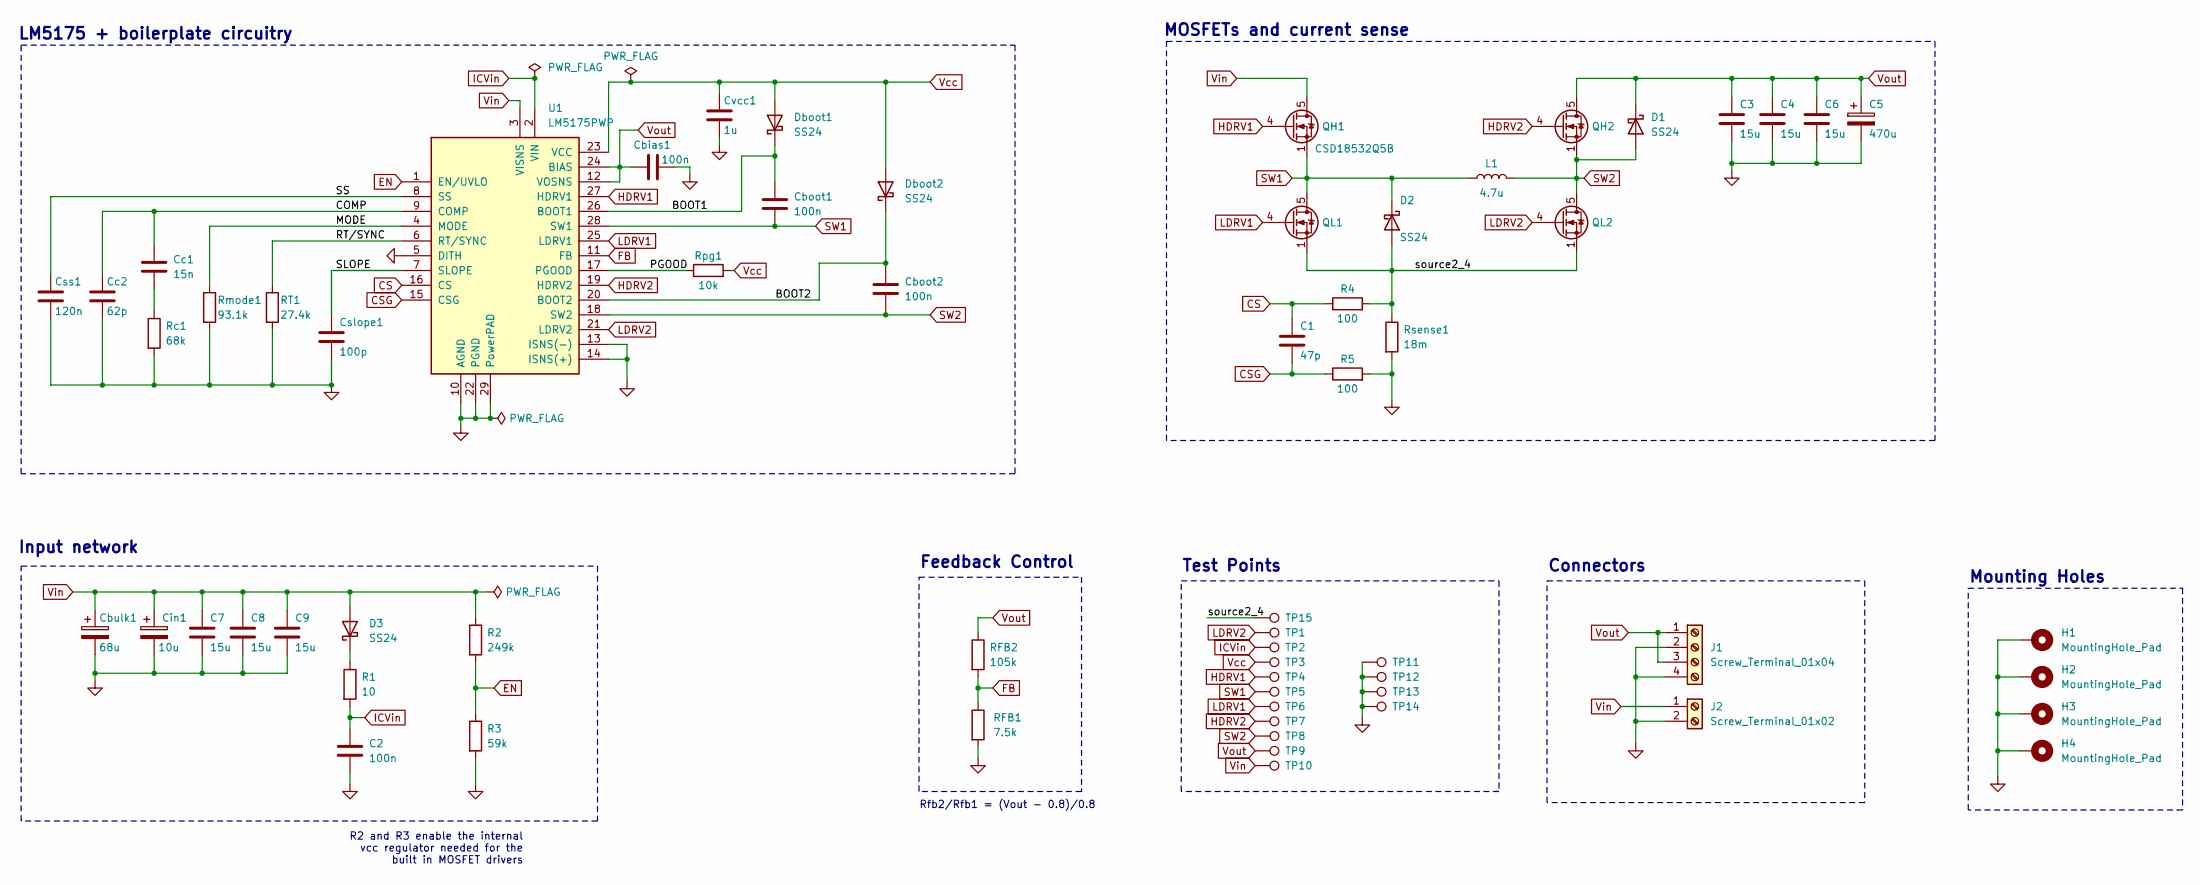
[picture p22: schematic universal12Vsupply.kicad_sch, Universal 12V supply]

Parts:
C1: 47p; C_0603_1608Metric_Pad1.08x0.95mm_HandSolder
C2: 100n; C_0805_2012Metric_Pad1.18x1.45mm_HandSolder
C3, C4, C6, C7, C8, C9: 15u; C_1206_3216Metric_Pad1.33x1.80mm_HandSolder
C5: 470u; CP_Elec_10x12.6
Cbias1: 100n; C_0805_2012Metric_Pad1.18x1.45mm_HandSolder
Cboot1, Cboot2: 100n; C_0805_2012Metric_Pad1.18x1.45mm_HandSolder
Cbulk1: 68u; CP_Elec_10x10.5
Cc1: 15n; C_0603_1608Metric_Pad1.08x0.95mm_HandSolder
Cc2: 62p; C_0603_1608Metric_Pad1.08x0.95mm_HandSolder
Cin1: 10u; CP_Elec_5x5.4
Cslope1: 100p; C_0603_1608Metric_Pad1.08x0.95mm_HandSolder
Css1: 120n; C_0603_1608Metric_Pad1.08x0.95mm_HandSolder
Cvcc1: 1u; C_0805_2012Metric_Pad1.18x1.45mm_HandSolder
D1, D2, D3: SS24; D_SMB_Handsoldering
Dboot1, Dboot2: SS24; D_SMB_Handsoldering
H1, H2, H3, H4: MountingHole_Pad; MountingHole_3.2mm_M3_Pad_Via
J1: Screw_Terminal_01x04; TerminalBlock_bornier-4_P5.08mm
J2: Screw_Terminal_01x02; TerminalBlock_bornier-2_P5.08mm
L1: 4.7u; L_Coilcraft_XAL1010-XXX_handsolder
QH1, QH2: CSD18532Q5B; TDSON-8-1
QL1, QL2: CSD18532Q5B; TDSON-8-1
R1: 10; R_0603_1608Metric_Pad0.98x0.95mm_HandSolder
R2: 249k; R_0603_1608Metric_Pad0.98x0.95mm_HandSolder
R3: 59k; R_0603_1608Metric_Pad0.98x0.95mm_HandSolder
R4, R5: 100; R_0603_1608Metric_Pad0.98x0.95mm_HandSolder
RFB1: 7.5k; R_0603_1608Metric_Pad0.98x0.95mm_HandSolder
RFB2: 105k; R_0603_1608Metric_Pad0.98x0.95mm_HandSolder
RT1: 27.4k; R_0603_1608Metric_Pad0.98x0.95mm_HandSolder
Rc1: 68k; R_0603_1608Metric_Pad0.98x0.95mm_HandSolder
Rmode1: 93.1k; R_0603_1608Metric_Pad0.98x0.95mm_HandSolder
Rpg1: 10k; R_0603_1608Metric_Pad0.98x0.95mm_HandSolder
Rsense1: 18m; R_2512_6332Metric_Pad1.40x3.35mm_HandSolder
TP1: LDRV2; TestPoint_THTPad_2.5x2.5mm_Drill1.2mm
TP2: ICVin; TestPoint_THTPad_2.5x2.5mm_Drill1.2mm
TP3: Vcc; TestPoint_THTPad_2.5x2.5mm_Drill1.2mm
TP4: HDRV1; TestPoint_THTPad_2.5x2.5mm_Drill1.2mm
TP5: SW1; TestPoint_THTPad_2.5x2.5mm_Drill1.2mm
TP6: LDRV1; TestPoint_THTPad_2.5x2.5mm_Drill1.2mm
TP7: HDRV2; TestPoint_THTPad_2.5x2.5mm_Drill1.2mm
TP8: SW2; TestPoint_THTPad_2.5x2.5mm_Drill1.2mm
TP9: Vout; TestPoint_THTPad_2.5x2.5mm_Drill1.2mm
TP10: Vin; TestPoint_THTPad_2.5x2.5mm_Drill1.2mm
TP11, TP12, TP13, TP14: gnd; TestPoint_THTPad_2.5x2.5mm_Drill1.2mm
TP15: source2_4; TestPoint_THTPad_2.5x2.5mm_Drill1.2mm
U1: LM5175PWP; HTSSOP-28-1EP_4.4x9.7mm_P0.65mm_EP3.4x9.5mm_ThermalVias

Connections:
/BOOT1: Cboot1.1, Dboot1.1 (K), U1.26 (BOOT1)
/BOOT2: Cboot2.1, Dboot2.1 (K), U1.20 (BOOT2)
/COMP: Cc1.1, Cc2.1, U1.9 (COMP)
/MODE: Rmode1.1, U1.4 (MODE)
/PGOOD: Rpg1.1, U1.17 (PGOOD)
/RT/SYNC: RT1.1, U1.6 (RT/SYNC)
/SLOPE: Cslope1.1, U1.7 (SLOPE)
/SS: Css1.1, U1.8 (SS)
/source2_4: D2.2 (A), QL1.1 (S), QL1.2 (S), QL1.3 (S), QL2.1 (S), QL2.2 (S), QL2.3 (S), R4.2, Rsense1.1, TP15.1
CS: C1.1, R4.1, U1.16 (CS)
CSG: C1.2, R5.1, U1.15 (CSG)
EN: R2.2, R3.1, U1.1 (EN/UVLO)
FB: RFB1.1, RFB2.2, U1.11 (FB)
GND: C2.2, C3.2, C4.2, C5.2, C6.2, C7.2, C8.2, C9.2, Cbias1.2, Cbulk1.2, Cc2.2, Cin1.2, Cslope1.2, Css1.2, Cvcc1.2, H1.1, H2.1, H3.1, H4.1, J1.2, J1.4, J2.2, R3.2, R5.2, RFB1.2, RT1.2, Rc1.2, Rmode1.2, Rsense1.2, TP11.1, TP12.1, TP13.1, TP14.1, U1.5 (DITH), U1.10 (AGND), U1.13 (ISNS(-)), U1.14 (ISNS(+)), U1.22 (PGND), U1.29 (PowerPAD)
HDRV1: QH1.4 (G), TP4.1, U1.27 (HDRV1)
HDRV2: QH2.4 (G), TP7.1, U1.19 (HDRV2)
ICVin: C2.1, R1.2, TP2.1, U1.2 (VIN)
LDRV1: QL1.4 (G), TP6.1, U1.25 (LDRV1)
LDRV2: QL2.4 (G), TP1.1, U1.21 (LDRV2)
unnamed: Cc1.2, Rc1.1
unnamed: D3.1 (K), R1.1
SW1: Cboot1.2, D2.1 (K), L1.1, QH1.1 (S), QH1.2 (S), QH1.3 (S), QL1.5 (D), TP5.1, U1.28 (SW1)
SW2: Cboot2.2, D1.2 (A), L1.2, QH2.1 (S), QH2.2 (S), QH2.3 (S), QL2.5 (D), TP8.1, U1.18 (SW2)
Vcc: Cvcc1.1, Dboot1.2 (A), Dboot2.2 (A), Rpg1.2, TP3.1, U1.23 (VCC)
Vin: C7.1, C8.1, C9.1, Cbulk1.1, Cin1.1, D3.2 (A), J2.1, QH1.5 (D), R2.1, TP10.1, U1.3 (VISNS)
Vout: C3.1, C4.1, C5.1, C6.1, Cbias1.1, D1.1 (K), J1.1, J1.3, QH2.5 (D), RFB2.1, TP9.1, U1.12 (VOSNS), U1.24 (BIAS)

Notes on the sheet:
R2 and R3 enable the internal vcc regulator needed for the built in MOSFET drivers
Feedback Control
MOSFETs and current sense
Rfb2/Rfb1 = (Vout - 0.8)/0.8
Mounting Holes
Input network
Connectors
LM5175 + boilerplate circuitry
Test Points

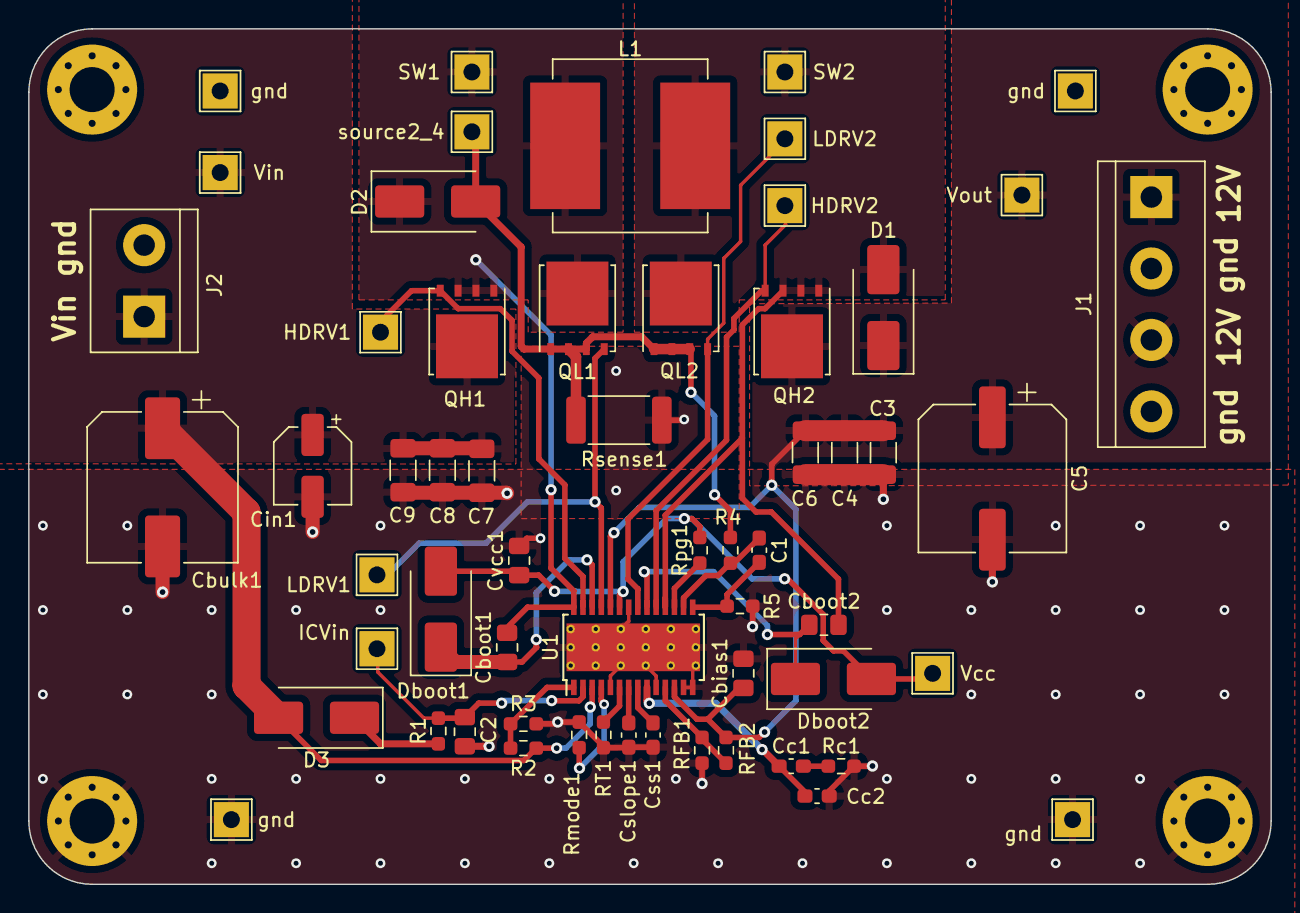
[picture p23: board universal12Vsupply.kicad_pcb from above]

Board: 2 copper layers, 88.3 x 60.8 mm, 63 parts (0 on the bottom side), 26 nets.

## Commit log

2023-11-04 added PCB constraints based on JLC PCB restraints
    [universal12Vsupply.kicad_pcb]
2023-11-04 started PCB layout
    [universal12Vsupply.kicad_pcb, universal12Vsupply.kicad_sch]
2023-11-04 'finalised' layout without DRC errors
    [universal12Vsupply.kicad_pcb, universal12Vsupply.kicad_sch]
2023-11-11 design clean up
    [universal12Vsupply.csv, universal12Vsupply.kicad_pcb, universal12Vsupply.kicad_sch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]
2023-11-11 added test points properly, DRC and ERC is fine
    [universal12Vsupply.kicad_pcb, universal12Vsupply.kicad_sch]
2023-11-11 added via stiching
    [universal12Vsupply.kicad_pcb]
2023-11-11 increased via stiching spacing
    [universal12Vsupply.csv, universal12Vsupply.kicad_pcb, universal12Vsupply.kicad_sch]
2023-11-15 finished PCB
    [universal12Vsupply.kicad_pcb, universal12Vsupply.kicad_sch]
2023-11-17 circuit changes, simulation, final (final) PCB layout and GERBER+drill files
    [universal12Vsupply-B_Cu.gbl, universal12Vsupply-B_Mask.gbs, universal12Vsupply-B_Paste.gbp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]
2023-11-17 repository organization
    [BOM.ods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]
2023-12-21 added design report i think
    [BOM.ods, universal12Vsupply.kicad_sch]
